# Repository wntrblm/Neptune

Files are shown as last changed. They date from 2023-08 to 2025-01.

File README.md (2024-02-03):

# Winterbloom Neptune

Neptune is a *salty* diode ladder filter.

More details available at https://winterbloom.com/shop/neptune

## Repository layout

This repository contains the hardware design files and user guide for Neptune:

- **factory/** contains the scripts used to program, test, and calibrate the module after assembly. These scripts are all written in Python.
- **hardware/** contains the hardware design files for the mainboard and blank panel, as well as hardware for automated testing. These are all created using KiCAD.
- **user_guide/** contains the user's guide source files. These are written in Markdown and published using MkDocs.
- **simulation/** contains the simulation used to design this filter. These should be opened using the Falstad CircuitJS simulator https://www.falstad.com/circuit/circuitjs.html.

## License and contributing

Neptune is open-source hardware and software, however, licensing a project like this is a little complicated. Please take a chance to review the [LICENSE](LICENSE.md) file.

We welcome contributions! Please read our [Code of Conduct](CODE_OF_CONDUCT.md) first.

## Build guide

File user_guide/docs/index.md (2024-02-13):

# Manual

Winterbloom's [Neptune][store-assembled] is a resonant diode ladder filter inspired by the designs of [Moritz Klein] and [Arturia]. It's intended to bring together sound and modulation into a complete, distinct synthesizer voice. Unlike typical multi-mode filters with separate modes or outputs, Neptune instead has separate low-pass and high-pass _inputs_ into a single filter core. This filter core is coupled with a feedback modulated distortion circuit called _salt_ that opens up a wide range of tonal possibilities from tame to dirty to outright chaotic.

[store-assembled]: https://winterbloom.com/shop/neptune
[store-kit]: https://winterbloom.com/shop/neptune-kit
[Moritz Klein]: https://www.youtube.com/@MoritzKlein0
[Arturia]: https://arturia.com

[TOC]

## Specifications

-   Available [assembled][store-assembled] or as a [kit][store-kit]
-   `12 HP`
-   `+12v @ 60 mA`, `-12v @ 50 mA`
-   `25mm` deep
-   Separate low pass & high pass inputs
-   Self-oscillating at high resonance levels
-   Salt feedback circuit
-   DC-coupled signal path
-   [ModularGrid page]

[modulargrid page]: https://www.modulargrid.net/e/winterbloom-neptune

## Getting support and help

We want you to have a wonderful experience with your module. If you need help or run into problems, please reach out to us. [Email] is the best way for product issues, whereas [Discord] and [GitHub][github issues] are great for getting advice and help on how to customize your module.

-   Send us [an email][email]
-   File a bug [on GitHub][github issues]
-   Reach out on the [Discord][discord]

[github issues]: https://github.com/wntrblm/Neptune/issues
[discord]: https://discord.gg/UpfqghQ
[email]: mailto:support@winterbloom.com

## Installation

Illustration of power connection

To install this into your Eurorack setup, connect a Eurorack power cable from your power supply to the back of the module. **Note that even though there's a keyed power connector on the module, double check that the red stripe is on the side labeled `red stripe`!** Once you've connected the power cable, secure your module to your rack rails using screws.

## Overview

Neptune illustration

Like other filters, Neptune _subtracts_ frequencies from audio signals. Unlike most other filters, however, Neptune is a single filter with separate inputs for low-pass and high-pass. If you use just one of these inputs at a time, Neptune will act as a familiar low-pass or high-pass filter. However, using both inputs at the same time opens up new possibilities for combining and filtering multiple signals.

Neptune is also a _resonant_ filter, which allows you to boost the frequencies around the cutoff frequency. Neptune rounds out its sonic character with _Salt_- a feedback modulation circuit that can add subtle grit when used sparingly and wild, chaotic distortion when applied with abandon.

Neptune belongs to _diode ladder_ family of filters. These filters are known for their characteristic "dirty" sound compared to the modern, popular "smooth" OTA family. Diode filters behave quite differently from their counterparts, exhibiting increasingly non-linear behavior when overdriven or operated with high resonance. Neptune itself shares a lot of similarities with the _Steiner_ filters found in Arturia's Brute series, but the addition of the salt feedback circuit allows for a broader range of unpredictable sounds.

Neptune is a collaboration between [Carson Walls] and [Winterbloom]. Carson crafted Neptune's voice, layout, and electronics design, while Thea & Maggie took on Neptune's visuals, interface, physical design, and manufacturing.

*[OTA]: Operational transconductance amplifier
[Carson Walls]: https://decapoddevices.com
[Winterbloom]: https://winterbloom.com

## Interface

### Audio inputs

Audio inputs

Neptune has separate audio inputs for low-pass and high-pass labeled with ++"lp"++ and ++"hp"++ respectively. Each input has its own volume control knob, where fully counterclockwise mutes the input. The mark at 2 o' clock indicates _unity gain_, where the input and output volume will be the same.

!!! fairy "Volume & resonance"
    Because of the architecture of this filter, the sound of the resonance is strongly affected by the input volume. The louder the input volume, the less obvious and "sweet" the resonance. If you want resonance to really catch the harmonics of the input, try reducing the input volume as you turn the resonance up.

### Audio output and volume

Audio output

Neptune's audio output, ++"out"++, has a built-in VCA for volume control. The ++"vol"++ input responds to a `0 to 5 V` signal with `0 V` completely muting the output and `5 V` giving maximum volume. When ++"vol"++ is left unpatched, the output volume defaults to maximum.

*[VCA]: Voltage-controlled amplifier

### Cutoff frequency

Cutoff frequency controls

Neptune dedicates several controls for the filter's _cutoff frequency_. Frequencies above the cutoff frequency are attenuated from the low-pass input signal, while frequencies below the cutoff are attenuated from the high-pass input signal.

The primary control for the cutoff frequency is the large cutoff knob labeled ++"♆"++. Turning the knob fully counterclockwise sets the cutoff frequency to near `0 Hz`, where the low-pass signal is almost entirely cut out while the high-pass signal is largely unaffected. Conversely, turning the knob fully clockwise sets the cutoff frequency to around `200 kHz`, where the low-pass signal is largely unaffected and the high-pass signal is cut out.

Audio inputs

The cutoff frequency set by the ++"♆"++ knob can be _modulated_ by two similar but distinct CV inputs labeled ++"fm1"++ and ++"fm2"++. Both inputs respond to `±5 V` signals but ++"fm1"++ has an _attenuverter_ while ++"fm2"++ has an _attenuator_.

The ++"fm1"++ _attenuverter_ controls both the _level_ and _polarity_ of ++"fm1"++'s CV input signal. At 12 o' clock, no signal is passed through. Turning clockwise gradually introduces the signal while turning counterclockwise gradually introduces an inverted version of the signal. The ring of LEDs around ++"fm1"++ indicate the polarity and level of modulation: blue indicates a positive signal, while red indicates a negative signal.

Similarly, the smaller ++"fm2"++ _attenuator_ controls just the _level_ of ++"fm2"++'s CV input signal. Fully counterclockwise completely attenuates the signal, while turning clockwise gradually introduces the signal. The white marking indicates where the cutoff frequency will roughly track at `1 Volt / octave`, but note that due to the way the filter works this will not track perfectly.

Finally, the LEDs around the ++"♆"++ knob indicate the total combined effect of ++"♆"++ along with the ++"fm1"++ & ++"fm2"++ inputs and controls. LEDs to the left of the knob indicate that more of the low-pass signal is being passed, while the LEDs to the right indicate that more of the high-pass signal is being passed.

!!! fairy "CV Range"
    Neptune's control voltages are nominally `±5 V`, but it's generally fine with voltages beyond this range. Just note that it may not respond as expected when you get far out of that range.

*[CV]: Control Voltage

### Resonance

Resonance controls

Neptune is a _resonant_ filter, and like other filters, resonance increases the volume of frequencies near the cutoff frequency. Neptune's resonance is controlled with the ++"reso"++ knob and CV input. The ++"reso"++ knob introduces more and more resonance as you turn the knob clockwise. When the ++"reso"++ knob is turned beyond the white dot the filter will begin self-oscillating, indicated with a red LED. Likewise, the ++"reso"++ CV input responds to `0 to 5 V` and is summed with the ++"reso"++ knob.

Unlike many filters, Neptune does not cut out bass frequencies as the resonance is turned up. While this preserves low-end frequencies, it can lead to the input volume overwhelming the resonance. If you want a "sweeter" resonance sound, try reducing the input volume when the resonance is turned up.

### Salt

Salt controls

Neptune includes a feedback modulation circuit called _Salt_. When used sparingly, salt can add a bit of subtle grit and sonic character to your sound. When used with gleeful abandon, salt will create increasingly chaotic distortion with harsh overtones.

Salt is controlled by the ++"salt"++ knob and CV input. The ++"salt"++ knob introduces more and more feedback modulation as you turn the knob clockwise. Keep in mind that salt and resonance are inherently linked and interact strongly, meaning that more resonance will increase salt's effect and vice versa. There are many textures to be found in different combinations of salt, resonance, and input volume.

## Example patches

If you're not sure where to start with Neptune this section has a few patches to get you up and running. Grab your patch cables, an oscillator, and an output module to follow along.

### Low-pass filter

The first patch creates a familiar *low-pass filter*:

Low pass filter patch

-   Turn the ++"reso"++ and ++"salt"++ knobs all the way counterclockwise
-   Turn the ++"♆"++ knob to 12 o' clock
-   Turn the small ++"lp"++ volume knob to about 2 o' clock
-   Patch an oscillator into the ++"lp"++ input jack
-   Patch the output jack to your rack's output or headphones module

Once patched, use the ++"♆"++ knob to sweep through the filter's frequency range. Try introducing some resonance using the ++"reso"++ knob and salt using the ++"salt"++ knob.

<winter-audio-player title="Low-pass filter sweep">
        <source src="./media/lp-sweep.flac" type="audio/flac" />
        <source src="./media/lp-sweep.m4a" type="audio/x-m4a" />
</winter-audio-player>
<winter-audio-player title="Resonant low-pass filter sweep">
    <source src="./media/resonant-lp-sweep.flac" type="audio/flac" />
    <source src="./media/resonant-lp-sweep.m4a" type="audio/x-m4a" />
</winter-audio-player>
<winter-audio-player title="Resonant, salty low-pass filter sweep">
    <source src="./media/resonant-salty-lp-sweep.flac" type="audio/flac" />
    <source src="./media/resonant-salty-lp-sweep.m4a" type="audio/x-m4a" />
</winter-audio-player>

### High-pass filter

The second patch is similar to the first and creates a *high-pass filter*:

High pass filter patch

-   Turn the ++"reso"++ and ++"salt"++ knobs all the way counterclockwise
-   Turn the ++"♆"++ knob to 12 o' clock
-   Turn the small ++"hp"++ volume knob to about 2 o' clock
-   Patch an oscillator into the ++"hp"++ input jack
-   Patch the output jack to your rack's output or headphones module

Once patched, use the ++"♆"++ knob to sweep through the filter's frequency range. Once again, try introducing some resonance using the ++"reso"++ knob and salt using the ++"salt"++ knob.

<winter-audio-player title="High-pass filter sweep">
    <source src="./media/hp-sweep.flac" type="audio/flac" />
    <source src="./media/hp-sweep.m4a" type="audio/x-m4a" />
</winter-audio-player>
<winter-audio-player title="Resonant high-pass filter sweep">
    <source src="./media/resonant-hp-sweep.flac" type="audio/flac" />
    <source src="./media/resonant-hp-sweep.m4a" type="audio/x-m4a" />
</winter-audio-player>
<winter-audio-player title="Resonant, salty high-pass filter sweep">
    <source src="./media/resonant-salty-hp-sweep.flac" type="audio/flac" />
    <source src="./media/resonant-salty-hp-sweep.m4a" type="audio/x-m4a" />
</winter-audio-player>

### High/low shelf filter

The next patch uses both inputs to create a high/low shelf filter:

High/low shelf filter patch

-   Turn the ++"reso"++ and ++"salt"++ knobs all the way counterclockwise
-   Turn the ++"♆"++ knob to 12 o' clock
-   Turn the small ++"lp"++ and ++"hp"++ volume knobs to about 12 o' clock
-   Using a multiple or stackcable, patch the *same* oscillator signal into both ++"lp"++ and ++"hp"++ input jacks
-   Patch the output jack to your rack's output or headphones module

Once patched, you can use the ++"lp"++ and ++"hp"++ volume knobs as your low- and high-pass shelves while the ++"Neptune ♆"++ knob controls the shelving frequency. You can use resonance as a frequency boost to *emphasize* the frequencies around the shelving frequency without cutting out the rest.

<winter-audio-player title="High/low shelf filter">
    <source src="./media/low-shelf-example.flac" type="audio/flac" />
    <source src="./media/low-shelf-example.m4a" type="audio/x-m4a" />
</winter-audio-player>

### Spectral crossfader

The next patch uses different signals on both inputs to create a *spectral* crossfader:

Spectral crossfader patch

-   Turn the ++"reso"++ and ++"salt"++ knobs all the way counterclockwise
-   Turn the ++"♆"++ knob to 12 o' clock
-   Turn the small ++"lp"++ and ++"hp"++ volume knobs to about 2 o' clock
-   Patch two different signals into the ++"lp"++ and ++"hp"++ input jacks
-   Patch the output jack to your rack's output or headphones module

Once patched, you can use the ++"♆"++ knob to crossfade between the frequency contents of the two signals, picking out the low frequencies of one signal and the high frequencies of the other.

<winter-audio-player title="High/low-pass crossfade">
    <source src="./media/lp-hp-crossfade.flac" type="audio/flac" />
    <source src="./media/lp-hp-crossfade.m4a" type="audio/x-m4a" />
</winter-audio-player>

### Self-oscillation

The final patch explores *self-oscillation*:

Self-oscillation patch

-   Leave the ++"lp"++ and ++"hp"++ input jacks unpatched
-   Turn the ++"salt"++ all the way counterclockwise
-   Turn the ++"♆"++ knob to around 10 or 11 o' clock
-   Turn the ++"reso"++ knob up to the self-oscillation point marked with the white dot, just past 2 o' clock
-   Patch the output jack to your rack's output or headphones module

Once patched, the filter should be self-oscillating and generating a sine waveform. You can use the ++"♆"++ knob to set the output signal's frequency. If you further increase resonance past the white dot, the waveform will saturate and become more harsh, like a square wave. Adding salt will cause the waveform to become more unstable and chaotic.

<winter-audio-player title="Clean self-oscillation">
    <source src="./media/clean-self-oscillation-sweep.flac" type="audio/flac" />
    <source src="./media/clean-self-oscillation-sweep.m4a" type="audio/x-m4a" />
</winter-audio-player>
<winter-audio-player title="Full self-oscillation">
    <source src="./media/full-self-oscillation-sweep.flac" type="audio/flac" />
    <source src="./media/full-self-oscillation-sweep.m4a" type="audio/x-m4a" />
</audio>
<winter-audio-player title="Salty self-oscillation">
    <source src="./media/salty-self-oscillation-sweep.flac" type="audio/flac" />
    <source src="./media/salty-self-oscillation-sweep.m4a" type="audio/x-m4a" />
</winter-audio-player>

## Further explorations

These ideas go beyond the example patches and may help you explore Neptune's uses and sonic possibilities.

### Basic synth voice

<winter-audio-player title="Basic low-pass synth voice">
    <source src="./media/simple-low-pass-filter-synth-voice-loop.flac" type="audio/flac" />
    <source src="./media/simple-low-pass-filter-synth-voice-loop.m4a" type="audio/x-m4a" />
</winter-audio-player>

Use any oscillator as the input for the ++"lp"++ in, preferably with a sharp waveform like a saw or square. Use an envelope going the ++"fm1"++ and ++"vol"++ inputs. Trigger the envelope with a gate source from a keyboard or sequencer. Adjust the envelope timings to get long drones notes, or quick percussive ones. Adjust the cutoff frequency, ++"fm1"++ amount, resonance, and salt to hear the range of possible sounds from the low-pass filter.

### Spectral crossfading synth voice

<winter-audio-player title="Spectral crossfading synth voice" loop>
    <source src="./media/crossfading-synth-voice-loop.flac" type="audio/flac" />
    <source src="./media/crossfading-synth-voice-loop.m4a" type="audio/x-m4a" />
</winter-audio-player>

Patch one oscillator to the ++"lp"++ input and another oscillator to the ++"hp"++ input, or use different waveforms from the same oscillator. Make sure the oscillators are tuned close to each other for the most harmonious sound. Listen to how the filter can fade between the frequencies of the two oscillator signals. Plug one envelope to ++"fm1"++ and a different envelope to ++"vol"++. Trigger the envelopes with the same gate source, such as a keyboard or sequencer. Try different envelope shapes to get different responses, and listen to how different input signals and volumes effect the sound. Try different oscillator tunings, at octaves or ratios for nice harmonic sounds, or detuned for more dissonant ones.

### Kick drum voice

<winter-audio-player title="Kick drum voice">
    <source src="./media/kick-drum-voice.flac" type="audio/flac" />
    <source src="./media/kick-drum-voice.m4a" type="audio/x-m4a" />
</winter-audio-player>

Leave the ++"lp"++ and ++"hp"++ inputs unpatched. Turn ++"reso"++ up until the filter starts self oscillating. Send a fast, exponential envelope to ++"fm1"++ input and a second slower envelope to ++"vol"++. The fast exponential envelope is the kick drum’s pitch sweep, whose intensity is adjusted with the ++"fm1"++ attenuverter. Adjust the cutoff frequency to set the base pitch of the drum sound, for example set it to around 9 o’clock for a low bass drum sound. Try increasing the resonance or adding salt to increase the grittiness of the drum.

### Chaotic oscillator

<winter-audio-player title="Chaotic oscillator">
    <source src="./media/chaotic-oscillation.flac" type="audio/flac" />
    <source src="./media/chaotic-oscillation.m4a" type="audio/x-m4a" />
</winter-audio-player>

Leave the ++"lp"++ and ++"hp"++ inputs unpatched and turn ++"reso"++ up until the filter starts self oscillating. Turn ++"salt"++ up until it *just* starts to get chaotic. The filter cutoff frequency will twist and wobble around, making a chaotic output which is a combination of feedback effects. Try adjusting the cutoff frequency, resonance, and salt to get a whole spectrum of sounds, from stable and harmonious, to wild and unstable.

### Drum effects

<winter-audio-player title="Drum effects">
    <source src="./media/drum-effects.flac" type="audio/flac" />
    <source src="./media/drum-effects.m4a" type="audio/x-m4a" />
</winter-audio-player>

Send a drum mix, such as a recording or a mix of synthesized drums, to both the ++"lp"++ and ++"hp"++ inputs. This will make the filter act like [a shelf filter](#highlow-shelf-filter). The ++"lp"++ and ++"hp"++ volume knobs act as the level for the low shelf and the high shelf, while the cutoff frequency controls the crossover point of the shelves. Try adding a bit of resonance, lowering the high pass volume a bit to make a low shelf filter, and adjusting the cutoff frequency to target specific frequencies in the drum mix. For example try to emphasizing the snare or getting rid of some of the high frequencies without cutting them out completely like on a traditional low pass filter.

### Loop crossfader

Use a device like an [Octatrack], [Digitakt], or any sampler that can output two different loops matched to the same tempo. If you only have a stereo output, you can hard-pan the loops to left and right channel before patching. Send one loop to the ++"lp"++ input and the other loop to the ++"hp"++ input. Adjusting the cutoff frequency will allow you to fade between the frequencies of the two loops. If the cutoff knob is fully clockwise you'll only hear the loop in the ++"lp"++ input, while if it's counterclockwise you'll only hear the loop in the ++"hp"++ input. You can adjust it to pick out the high frequencies of one loop, such as the cymbals, and the low frequencies of another loop, such as the bass drum.

[Octatrack]: https://www.elektron.se/us/octratrack-mkii-explorer
[Digitakt]: https://www.elektron.se/us/digitakt-explorer

### CV filter

Neptune is *technically* DC-coupled, so will pass and filter CV signals just as it does audio signals. If you send a signal to the ++"lp"++ input then Neptune will act like a *slew limiter*, limiting how fast the signal can move. If you use the ++"hp"++ input then Neptune will act like a gate to trigger converter, where sudden changes will be passed through but the output will settle back to the value at the ++"lp"++ input. Increasing resonance will cause Neptune to overshoot the input value and "ring".

Note that while Neptune can do some fun stuff with CV, it's very much designed with audio in mind which brings some limitations. First, the lowest cutoff frequency that the ++"♆"++ knob can reach is around `5 Hz`, however, you can use the ++"fm1"++ input along with its attenuverter to push the cutoff frequency even lower. Second, Neptune wasn't really designed for DC accuracy so it won't work well with sensitive CV signals like `1 V / Octave` pitch signals. Finally, Neptune's output can have a DC offset of up to `±2 V`, however, you can mitigate this a bit by mixing a constant voltage in with the ++"lp"++ input.

## Open source hardware & software

Neptune is completely open source and hacking is encouraged.

The [hardware design][hardware source] is available under the permissive [CERN-OHL-P v2] license, and is designed using [KiCAD], which is also free and open source. You can open the hardware files using [KiCAD], or you can download a PDF of the [schematics].

Open Source Hardware Association mark Neptune is [certified open source hardware][oshwa certification].

[hardware source]: https://github.com/wntrblm/Neptune/tree/main/hardware
[schematics]: https://github.com/wntrblm/Neptune/raw/main/hardware/board/mainboard.pdf
[CERN-OHL-P v2]: https://cern-ohl.web.cern.ch/
[KiCAD]: https://kicad.org/
[oshwa certification]: https://certification.oshwa.org/us002605.html

## Warranty, disclaimers, and limits

Modules purchased from Winterbloom have a warranty of six months from the date of purchase. This warranty covers any manufacturing defects in the module. It does not cover damage due to incorrect handling, storage, power, overvoltage events, or modifications.

Please [contact us][email] if you are experiencing issues with your module. Modules returned under warranty will either be refunded, replaced, or repaired at our discretion. You will be responsible for the cost of returning the module to Winterbloom.

Because Eurorack has a vast number of possible combinations of power supplies, modules, cases, and accessories, it is impossible for us to guarantee compatibility with every possible configuration. We make a reasonable effort to test modules with several power supplies, cases, and other modules.

We encourage tinkering, however, we will not refund, repair, or replace any products that have been modified.

We have stress tested Neptune under the following conditions. These are provided for reference only; we do not guarantee that the module will function under these conditions.

-   Continuous run time: at least `48 hours`
-   Overvoltage from power supply: at least `±20 V`
-   Reverse voltage from power supply: at least `±24 V`
-   Undervoltage from power supply: as low as `±8 V`
-   Over and under voltage on inputs: at least `±11 V`
-   Output shorted to ground: at least `60 minutes`

[email]: mailto:support@winterbloom.com

## Acknowledgments and thanks

Neptune would not be possible without the excellent educational YouTube videos by [Moritz Klein], and the help of him and others on his discord server. We would also like to acknowledge the following individuals for their outstanding support:

- Sarah Ocean, for coming up with the name "Salt"
- Izaak Hollander, for endless enthusiasm and beta testing
- Ben Wilson, for being a well of knowledge and incredible talent
- Jeremy Leaird-Koch, for wringing delights from Neptune in ways only he could
- Stijn & Priscilla Haring-Kuipers, for their guidance and insight

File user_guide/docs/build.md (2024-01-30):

---
title: Kit build guide
---

# Build

Welcome to the build guide for Neptune's DIY kit. We hope you have a great time putting this module together and a wonderful time using it.

Please **read all instructions** thoroughly before starting. If you have questions or run into trouble please reach out to us on [discord] or drop us [an email][email].

This is a **beginner level** kit. Some soldering experience is helpful but not required, though we recommend practicing on another project first. We also have some slightly easier kits available, such as our [Helium kit]. Even if you've got some experience, we recommend taking a look at [Adafruit's guide to excellent soldering][adafruit soldering guide].

This build takes around **one hour** to complete.

[TOC]

[discord]: https://discord.gg/UpfqghQ
[email]: mailto:support@winterbloom.com
[Helium kit]: https://winterbloom.com/shop/helium-kit
[adafruit soldering guide]: https://learn.adafruit.com/adafruit-guide-excellent-soldering

## Tools required

Before you begin, make sure that you've got:

-   Safety glasses. Yes, **really**. A pair like [these][safety glasses] are fine.
-   Proper ventilation, like this [small filtered fan](https://a.co/d/eUfPCRO).
-   A **temperature-controlled** soldering iron, like this [Hakko] or the [Pinecil]. It is very important to use a temperature-controlled iron, since unregulated irons can easily get hot enough to damage components. You should set your iron temperature based on your solder manufacturer's recommendations.
-   Solder. We recommend [Adafruit's SAC305 solder][adafruit solder] or [Kester 275 K100LD].
-   A small flat head screwdriver, like [this one][small screwdriver].

!!! question "Flux"
    We suggest using solder with "no clean" flux. If you use a different kind of flux, be sure to carefully clean the flux residue off based on the guidelines provided by the manufacturer of your solder. Take special care with the LEDs and potentiometers, as they can be damaged by water and flux cleaners.

[safety glasses]: https://a.co/d/dMXvPP6
[tweezers]: https://www.adafruit.com/product/422
[Hakko]: https://www.adafruit.com/product/1204
[Pinecil]: https://pine64.com/product/pinecil-smart-mini-portable-soldering-iron/
[adafruit solder]: https://www.adafruit.com/product/734
[Kester 275 K100LD]: https://www.kester.com/products/product/275-flux-cored-wire
[flux pen]: https://www.sra-solder.com/sra-312-no-clean-flux-pen-refillable
[small screwdriver]: https://lovemyswitches.com/2mm-flat-head-screwdriver-for-knob-set-screws/

## Kit contents

Your kit should contain the following items. If any are missing please [email us][email].

<winter-image-map src="../images/kit/kit-contents.svg">
    <winter-image-map-item id="mainboard">Mainboard</winter-image-map-item>
    <winter-image-map-item id="faceplate">Faceplate</winter-image-map-item>
    <winter-image-map-item id="jacks">1/8" jacks (8)</winter-image-map-item>
    <winter-image-map-item id="jack-nuts">Hex nuts for the 1/8" jacks (8)</winter-image-map-item>
    <winter-image-map-item id="power-header">Eurorack power header</winter-image-map-item>
    <winter-image-map-item id="rubber-bands">Rubber bands (2)</winter-image-map-item>
    <winter-image-map-item id="big-knob">Big knob</winter-image-map-item>
    <winter-image-map-item id="small-knob">Small knobs (3)</winter-image-map-item>
    <winter-image-map-item id="trimpots">Tall trimmer pots (3)</winter-image-map-item>
    <winter-image-map-item id="pots">9mm pots (4)</winter-image-map-item>
    <winter-image-map-item id="pot-washers">Washers for 9mm pots (4)</winter-image-map-item>
    <winter-image-map-item id="pot-nuts">Nuts for 9mm pots (4)</winter-image-map-item>
</winter-image-map>

- (1) Mainboard
- (1) Faceplate
- (8) 1/8" jacks
- (8) Hex nuts for the 1/8" jacks
- (3) Tall trimmer pots
- (4) 9mm pots
- (4) Washers & nuts for the 9mm pots
- (3) Small knobs
- (1) Large knob
- (1) Eurorack power header
- (2) Rubber bands

!!! fairy "Pot washers?"
    We typically screw the 9mm pot's washer and nut onto the shaft when packing kits so they don't get lost. You should remove them before you start the build!

## Power header

Your first task is to solder the 10-pin Eurorack power connector to the mainboard.

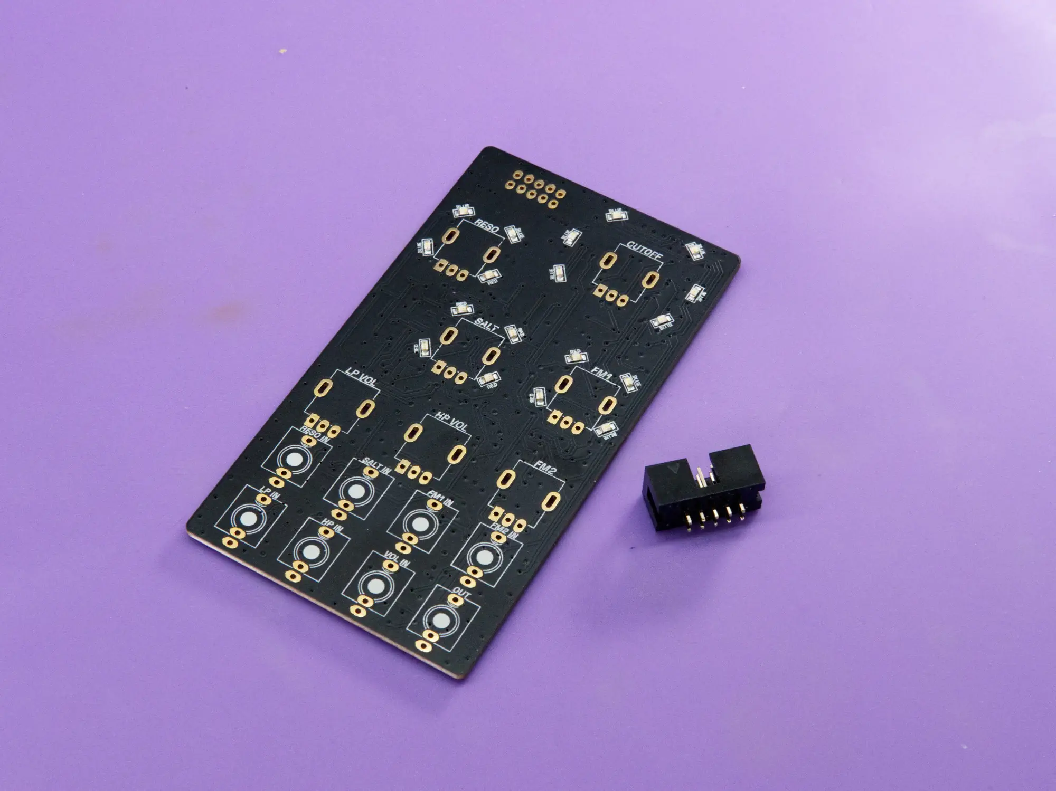
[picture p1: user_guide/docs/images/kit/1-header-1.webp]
Power header and mainboard


The power connector goes on the **back** side of the board. When placing **note the notch in the outline on the board**. You'll need to make sure the **slot on the connector matches where the notch is on the outline**. The holes for the power connector are designed to be a tight fit, so make sure to push the header firmly flush against the board.

<winter-carousel>
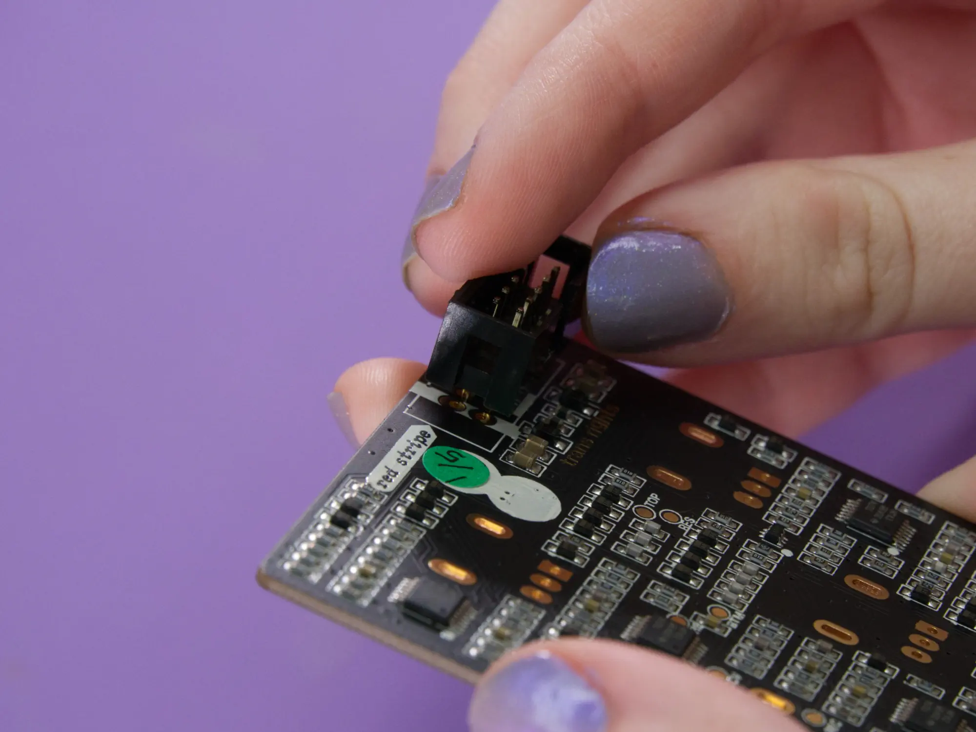
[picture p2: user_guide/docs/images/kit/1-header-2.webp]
  
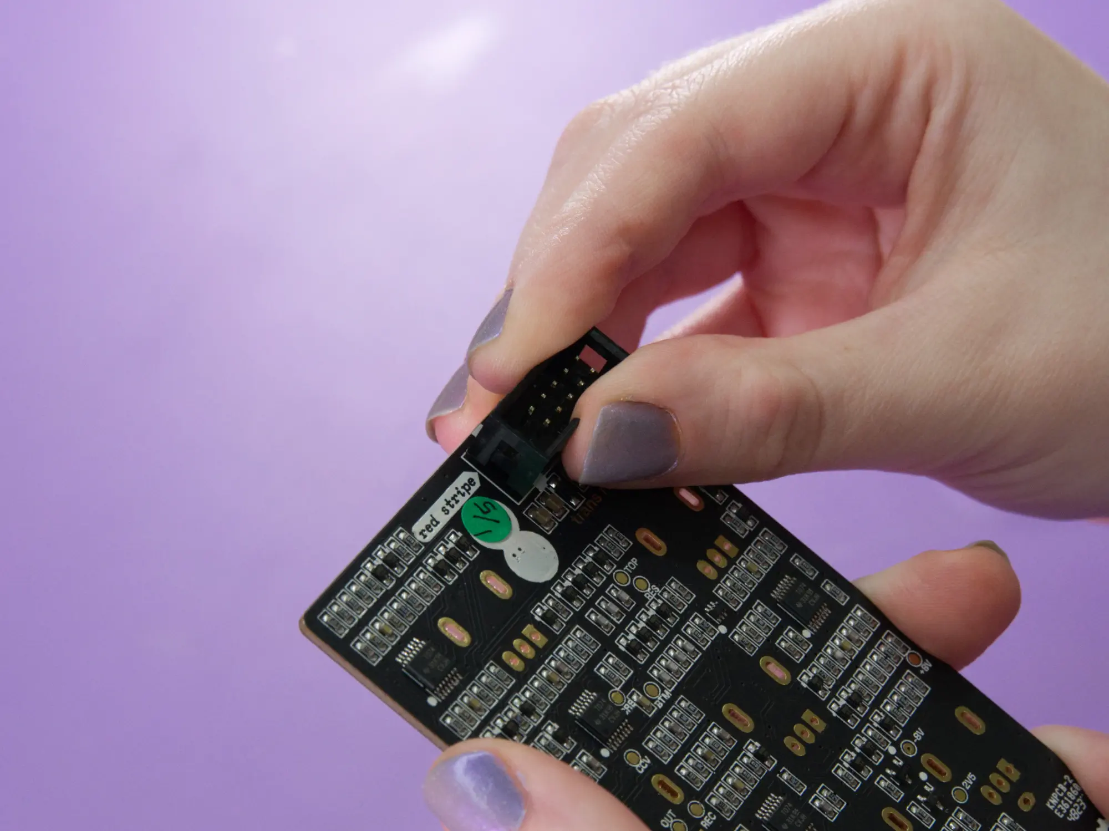
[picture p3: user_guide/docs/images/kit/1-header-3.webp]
  
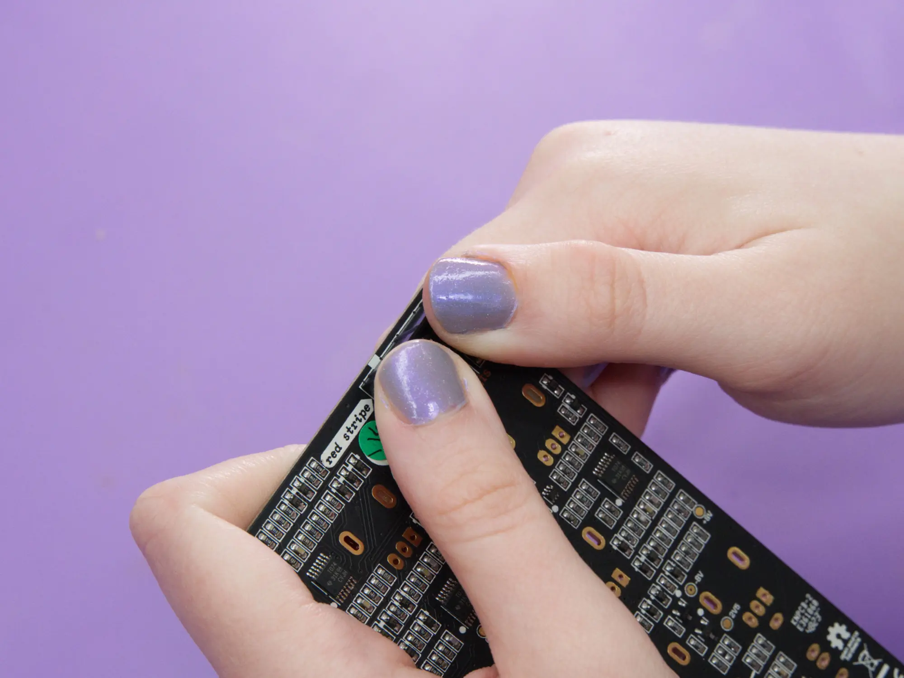
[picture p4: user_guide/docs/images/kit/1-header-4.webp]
  
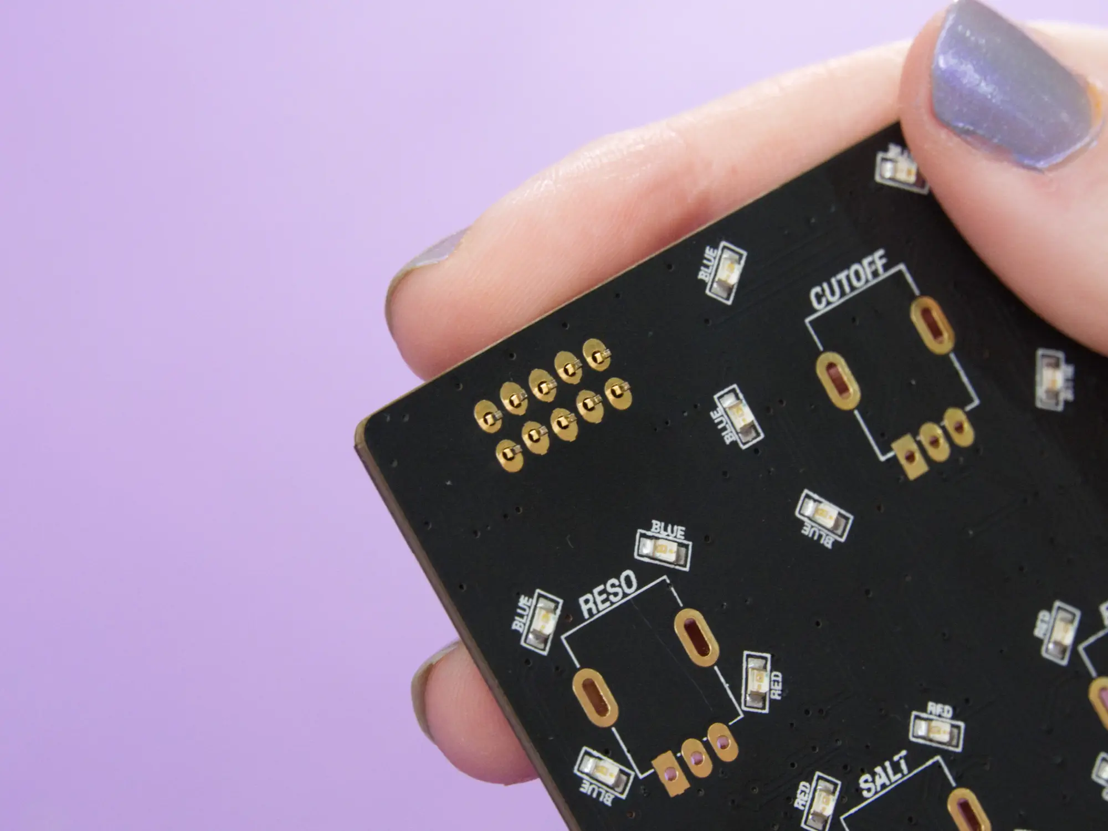
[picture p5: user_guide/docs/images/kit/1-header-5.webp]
  
</winter-carousel>

Once placed, make sure to push it flush against the board and then solder the 10 pins on the front side of the board.

<winter-carousel>
  
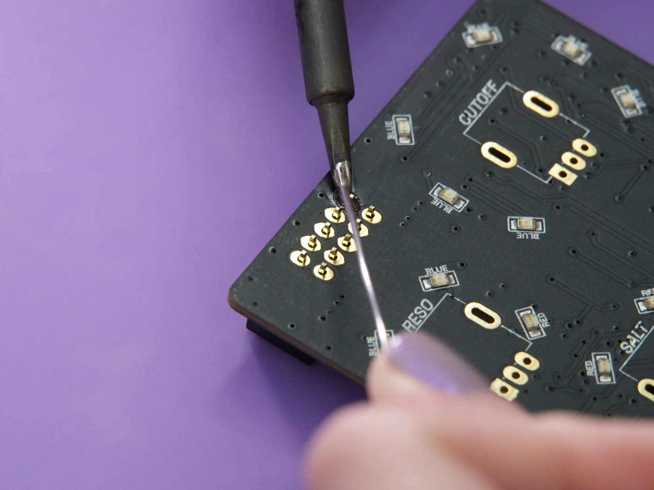
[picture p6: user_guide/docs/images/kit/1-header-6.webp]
  
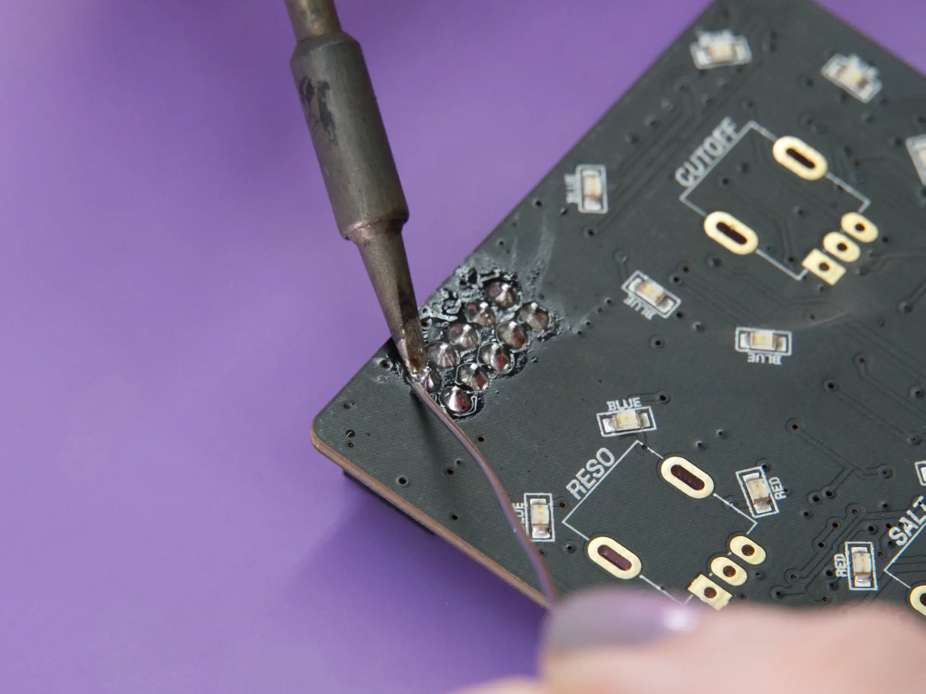
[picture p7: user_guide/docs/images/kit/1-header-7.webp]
  
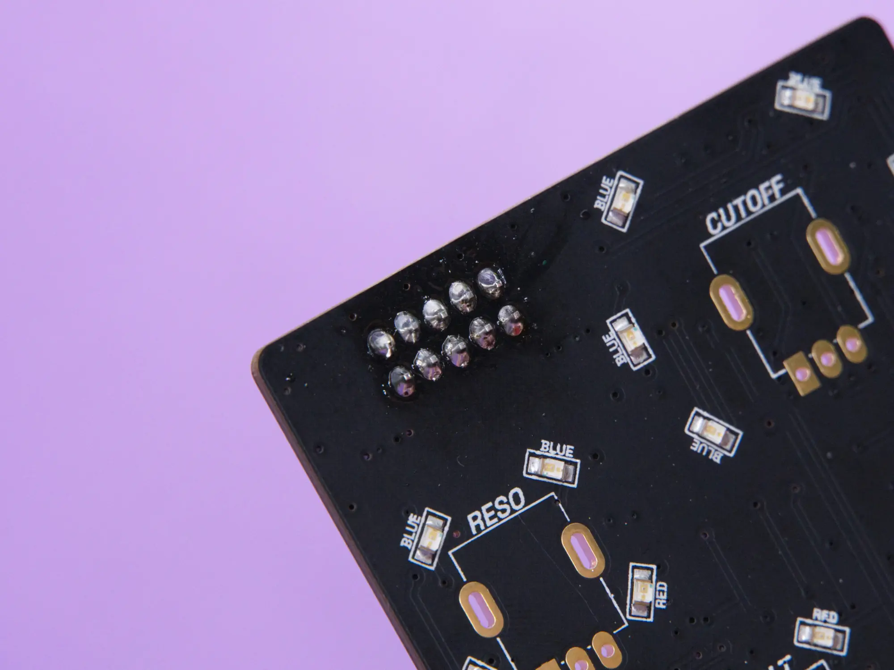
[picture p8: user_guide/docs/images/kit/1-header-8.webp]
  
</winter-carousel>

!!! warning "Watch out for those LEDs!"
    Avoid touching the LEDs with your iron- they really don't like being melted and they're very hard to replace.

## Pots and jacks

Your next task is to put all of the jacks and pots into place. **Don't solder these yet**, as you'll use the faceplate to help you get everything aligned in the next step.

!!! fairy "Stuffing"
    Fun fact, we call this process "stuffing"! It makes us think of Thanksgiving. 🦃

Start with the four `9mm pots`. Place them onto upper area of mainboard in the spots labeled `cutoff`, `reso`, `salt`, and `fm1`. You may need to bend or straighten the mounting legs on the pots to get them in place.

<winter-carousel>
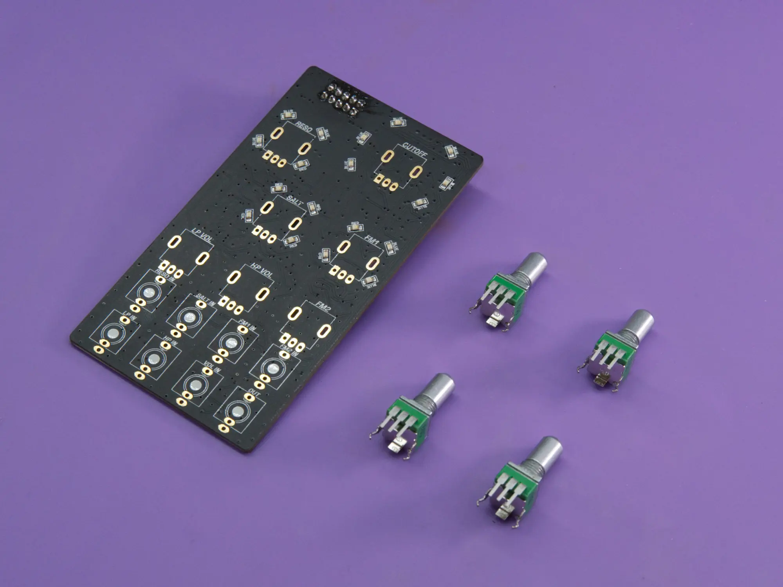
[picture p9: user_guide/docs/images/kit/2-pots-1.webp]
  
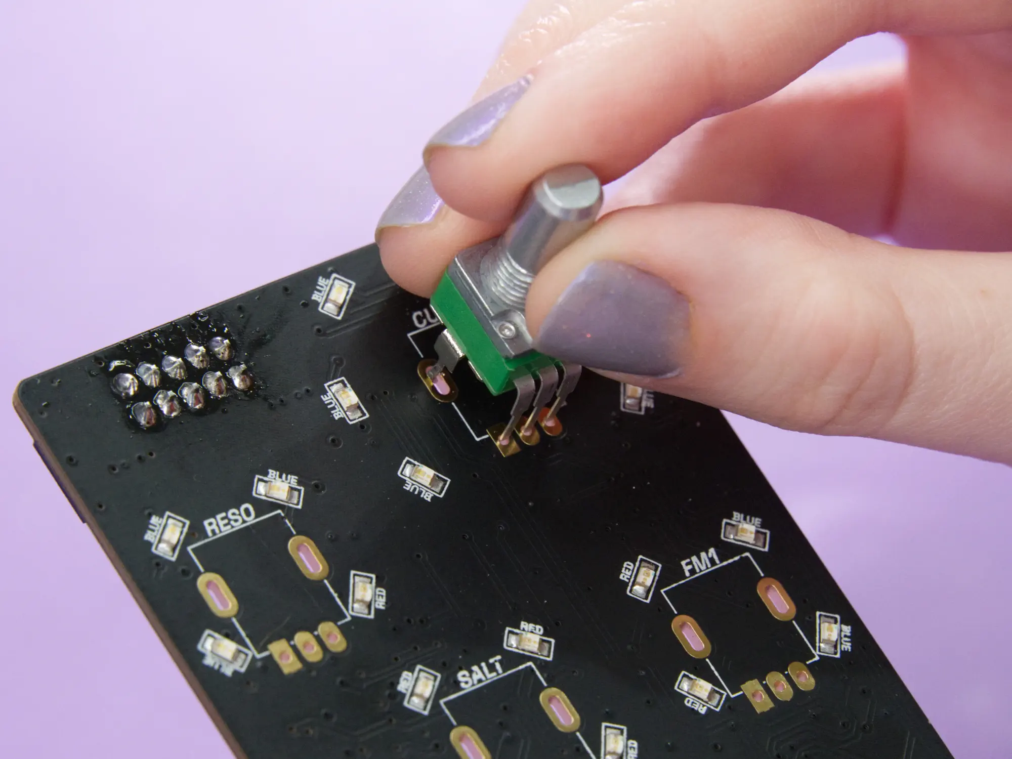
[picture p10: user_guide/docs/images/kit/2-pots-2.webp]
  
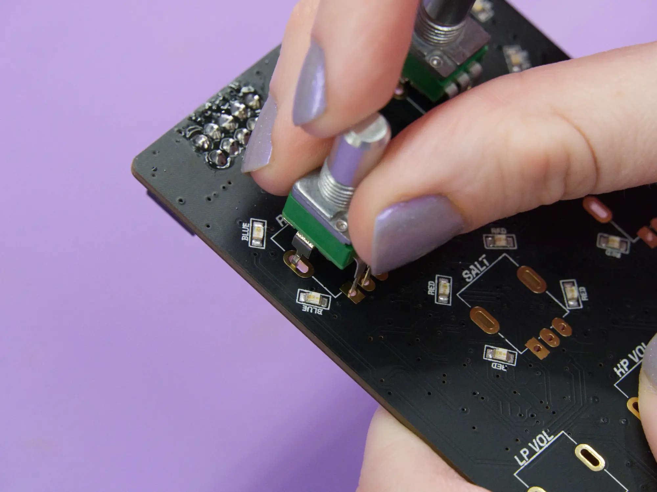
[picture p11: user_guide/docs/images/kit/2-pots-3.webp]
  
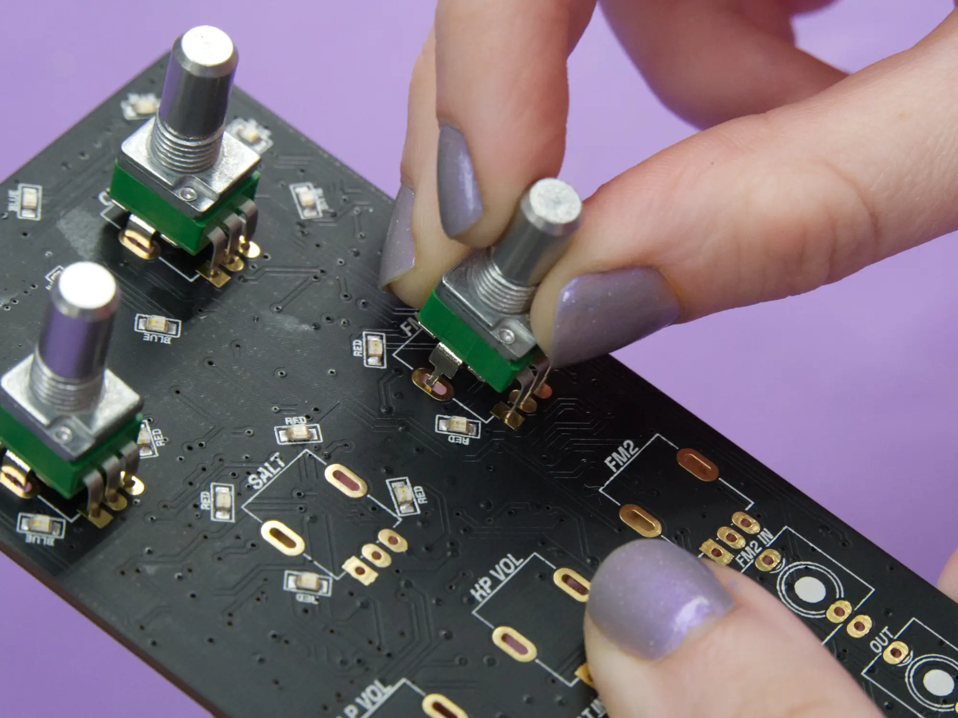
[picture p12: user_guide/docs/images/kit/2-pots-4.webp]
  
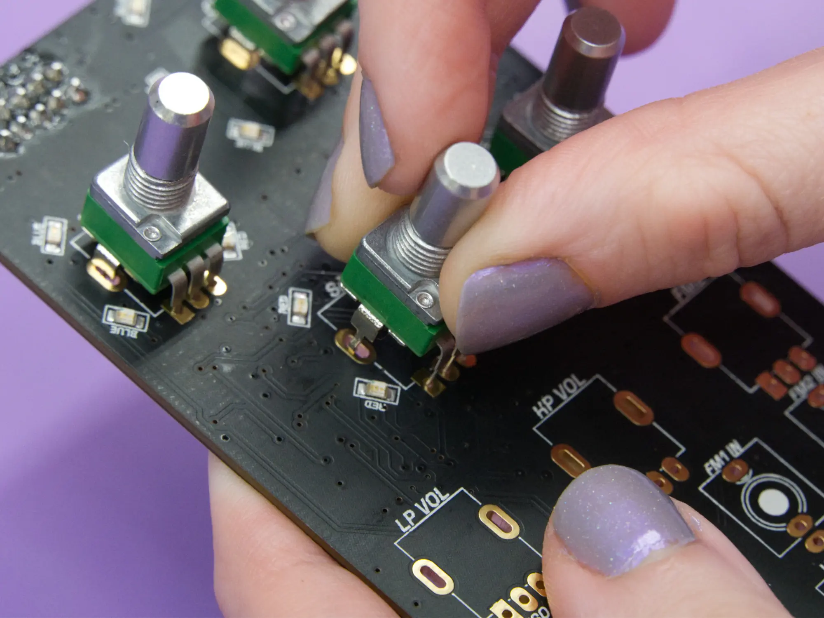
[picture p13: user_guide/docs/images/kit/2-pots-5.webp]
  
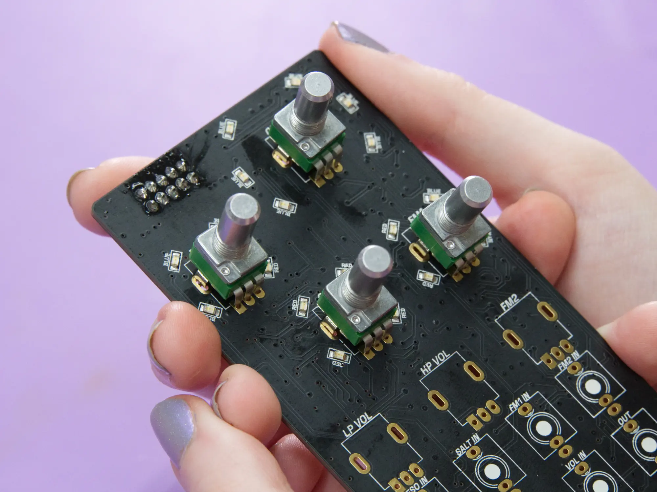
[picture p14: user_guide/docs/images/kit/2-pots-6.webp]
  
</winter-carousel>

Next up is the 3 `Tall trimmer pots`. Place these into the three spots in the middle of the mainboard labeled `lp vol`, `hp vol`, and `fm2`.

<winter-carousel>
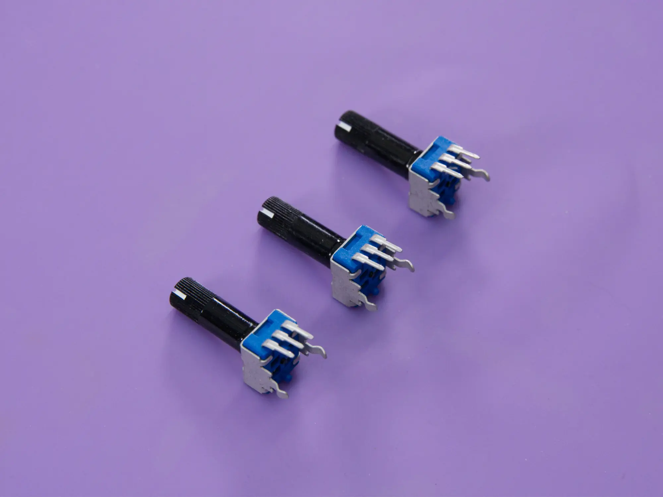
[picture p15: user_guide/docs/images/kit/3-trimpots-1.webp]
  
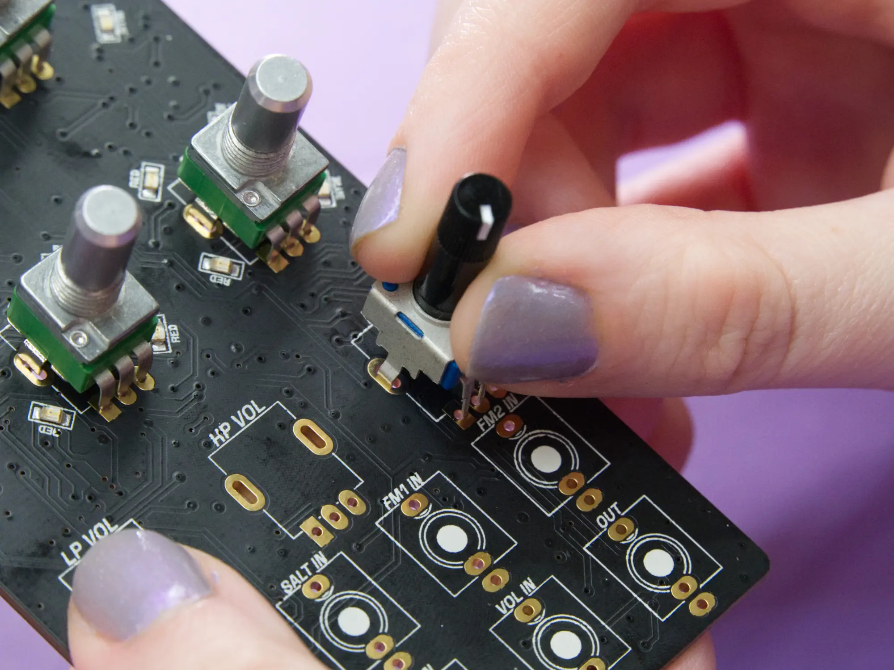
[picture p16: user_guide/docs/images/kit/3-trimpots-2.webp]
  
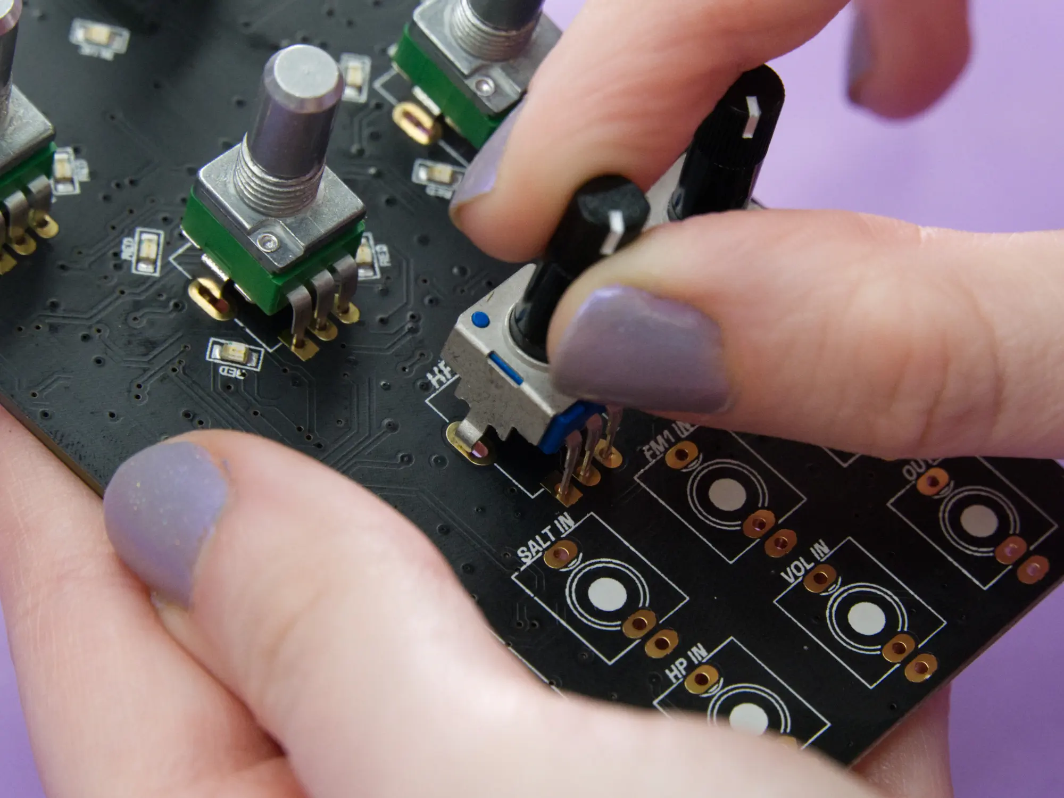
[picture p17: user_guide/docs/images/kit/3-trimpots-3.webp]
  
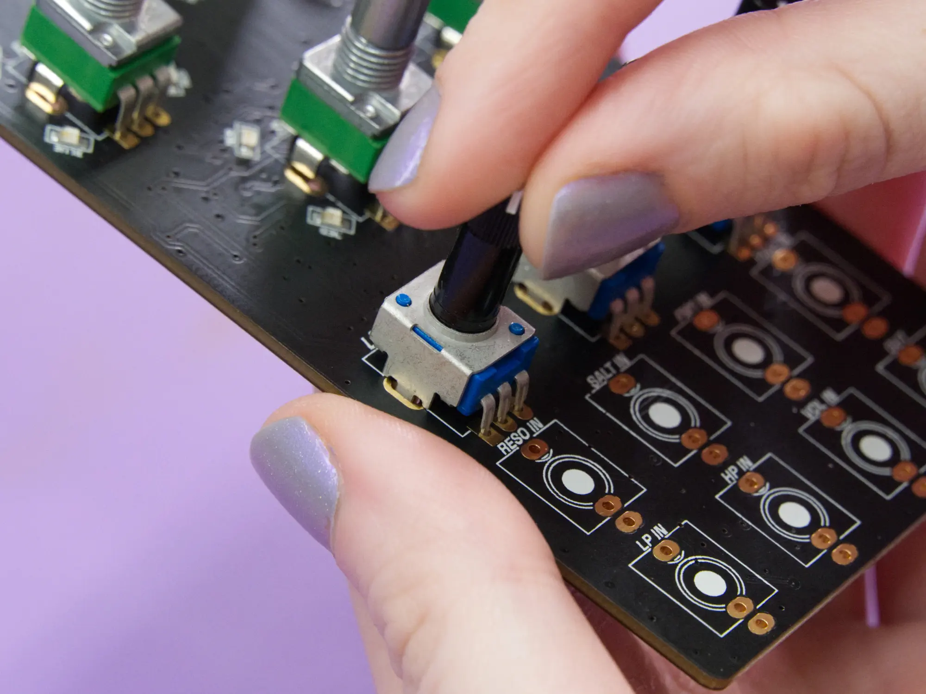
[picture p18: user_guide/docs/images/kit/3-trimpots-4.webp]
  
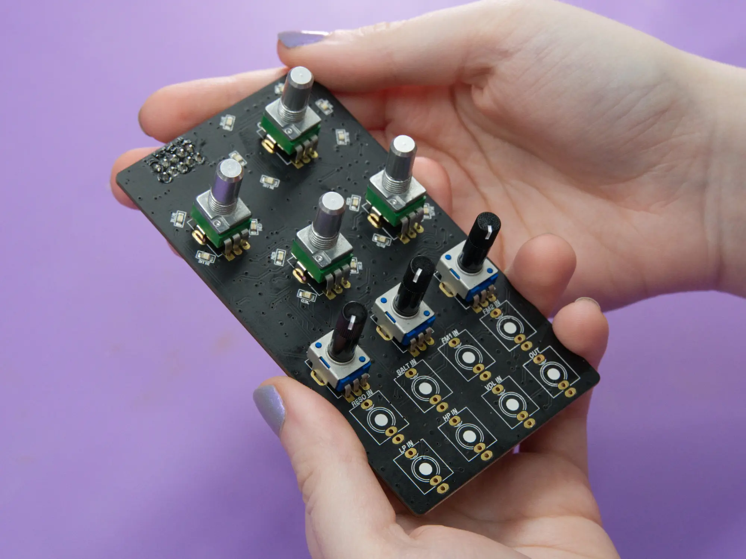
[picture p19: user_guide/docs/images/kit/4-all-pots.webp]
  
</winter-carousel>

Finally, the `1/8" jacks`. These go on the lower area of the mainboard in the spots labeled `reso in`, `salt in`, `fm1 in`, `fm2 in`, `lp in`, `hp in`, `vol in`, and `out`.

<winter-carousel>
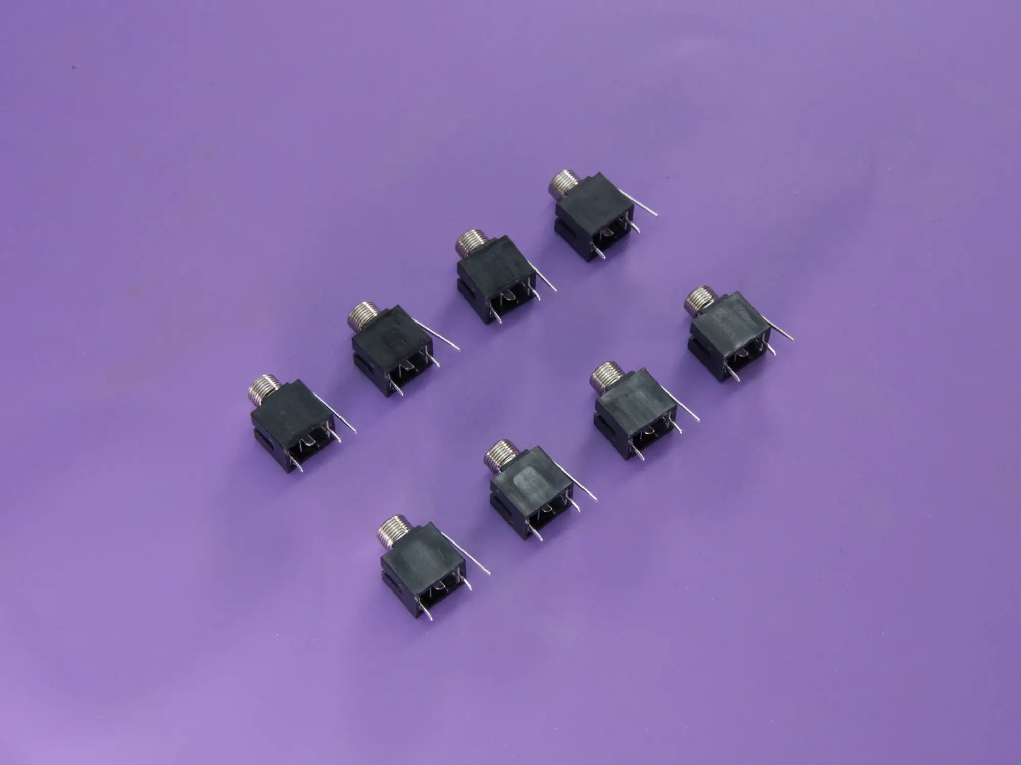
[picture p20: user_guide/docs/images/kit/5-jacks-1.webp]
  
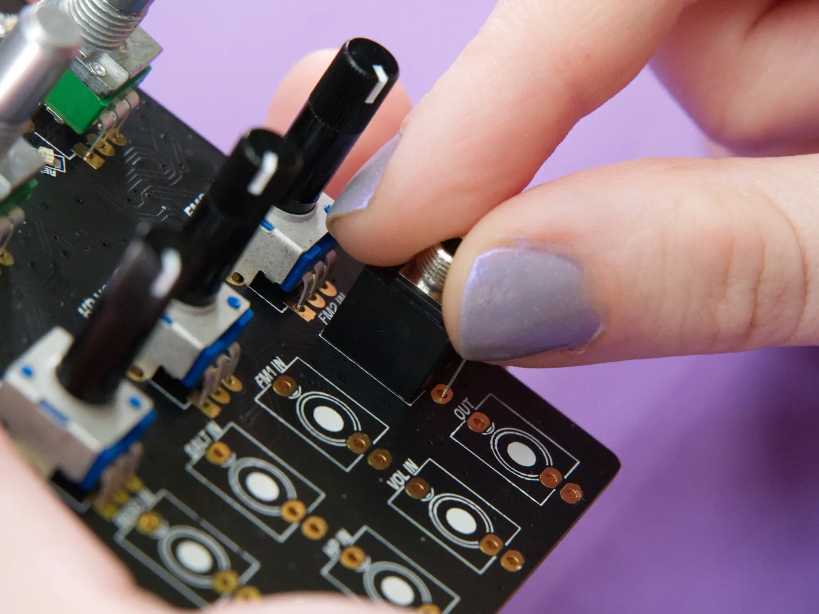
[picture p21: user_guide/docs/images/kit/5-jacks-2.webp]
  
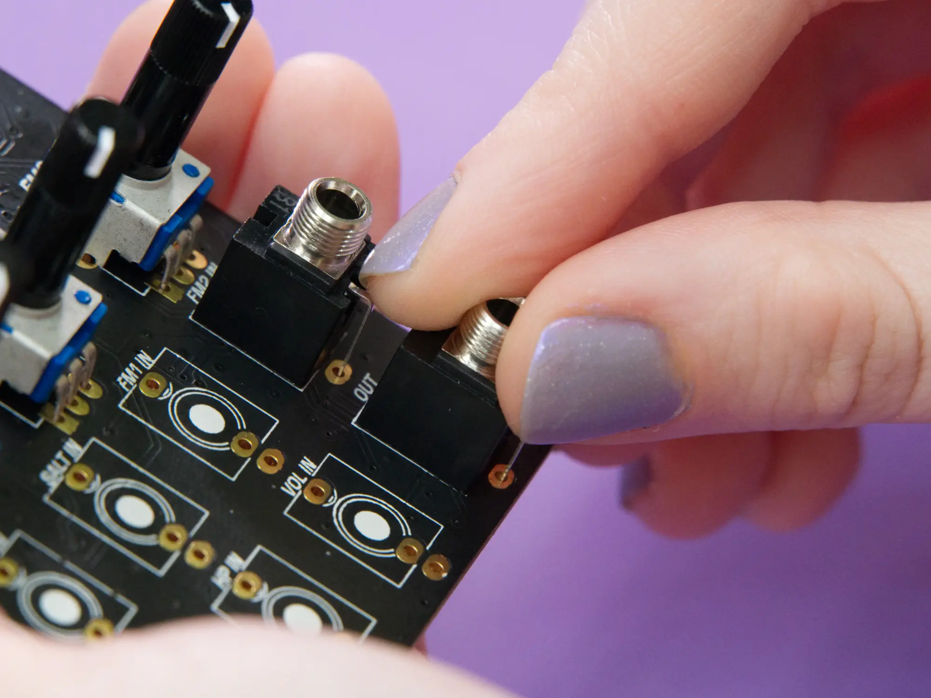
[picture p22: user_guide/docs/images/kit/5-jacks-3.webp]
  
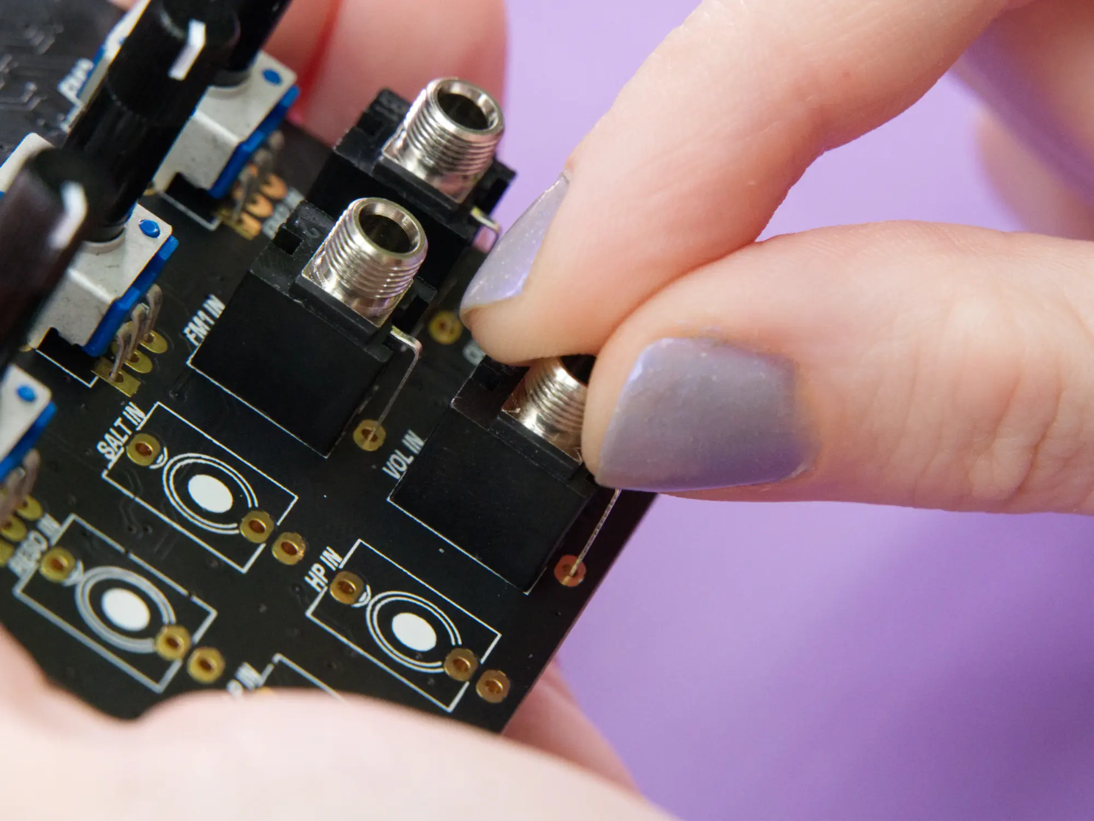
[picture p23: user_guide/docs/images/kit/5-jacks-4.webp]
  
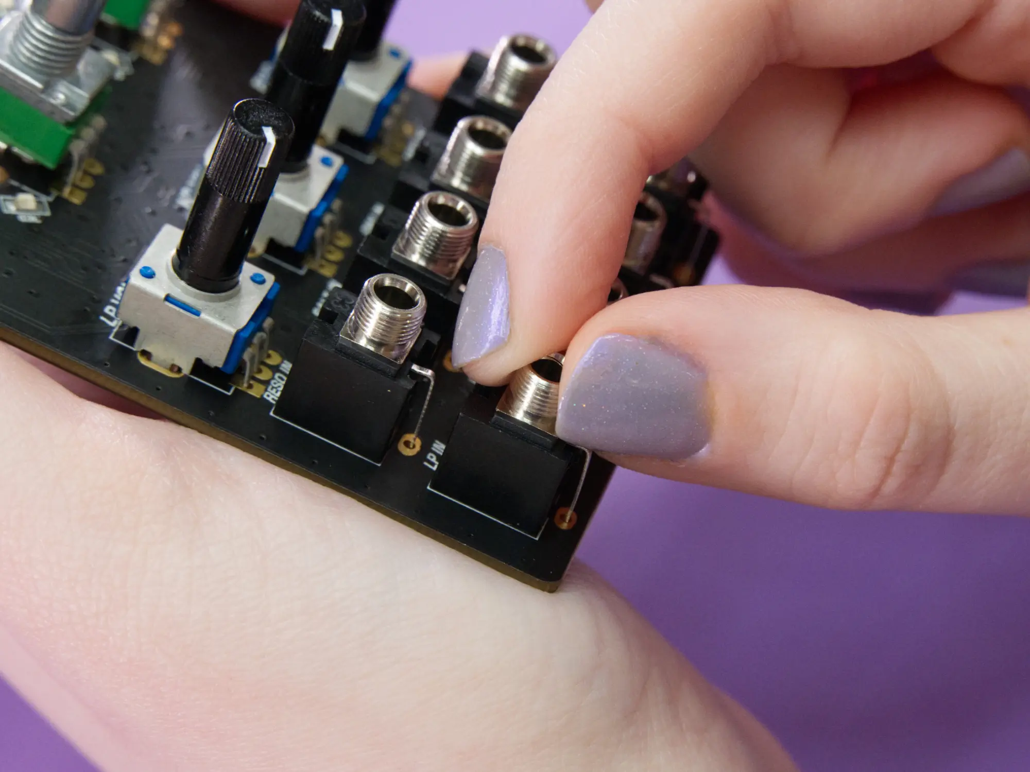
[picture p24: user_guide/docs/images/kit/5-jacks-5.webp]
  
</winter-carousel>

At this point you should have all the jacks and pots in place:

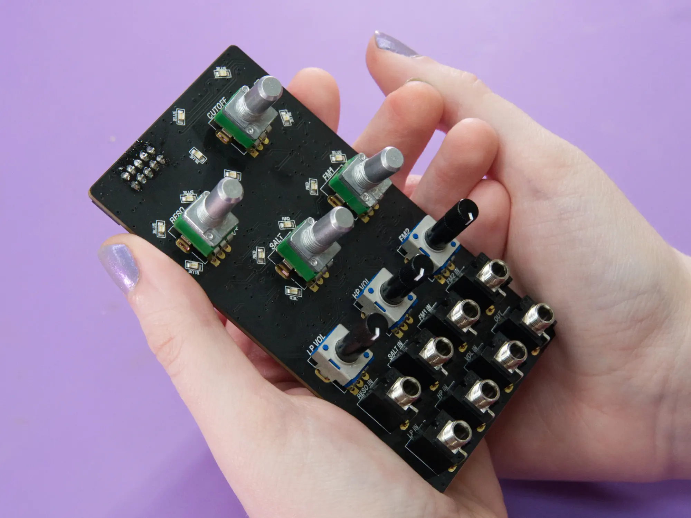
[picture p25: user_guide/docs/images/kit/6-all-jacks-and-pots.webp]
All things stuffed


## Faceplate alignment

Before you get down to soldering, your next task is to use the faceplate to make sure everything is aligned and hold it all in place while you work. Grab the `faceplate` and the two `rubber bands` and then carefully place the faceplate over the jacks and pots.

<winter-carousel>
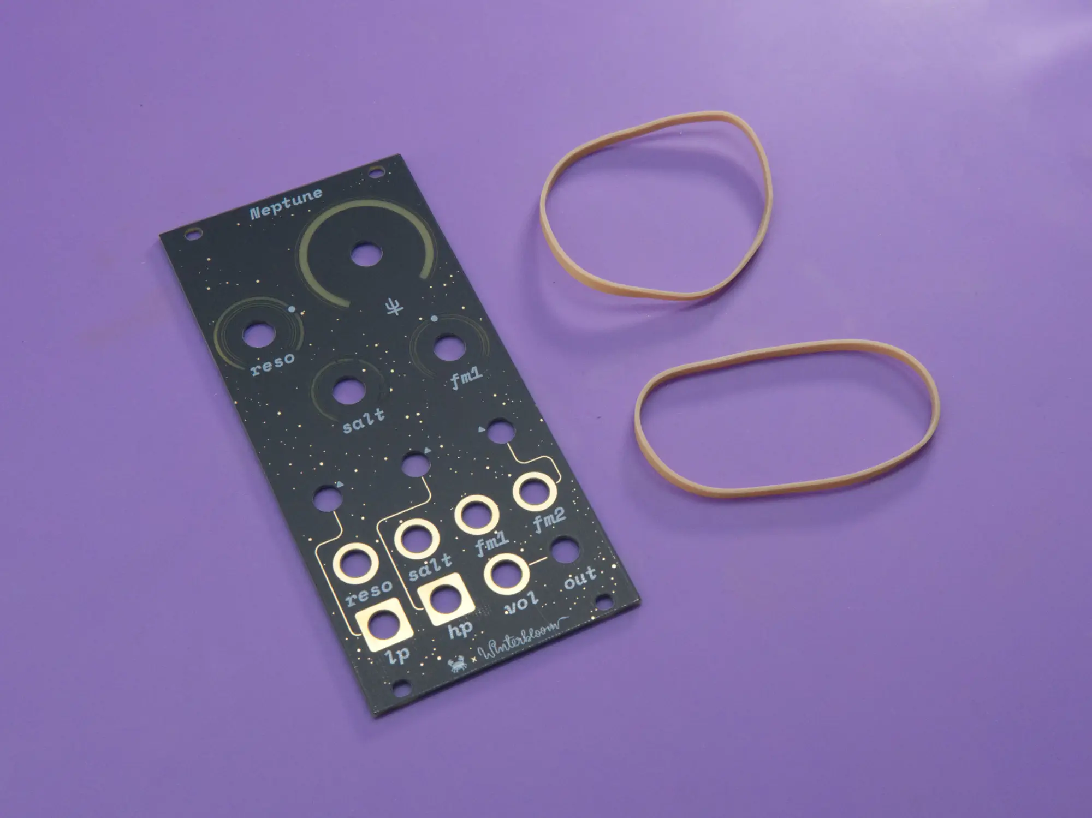
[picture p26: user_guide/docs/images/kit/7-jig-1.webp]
  
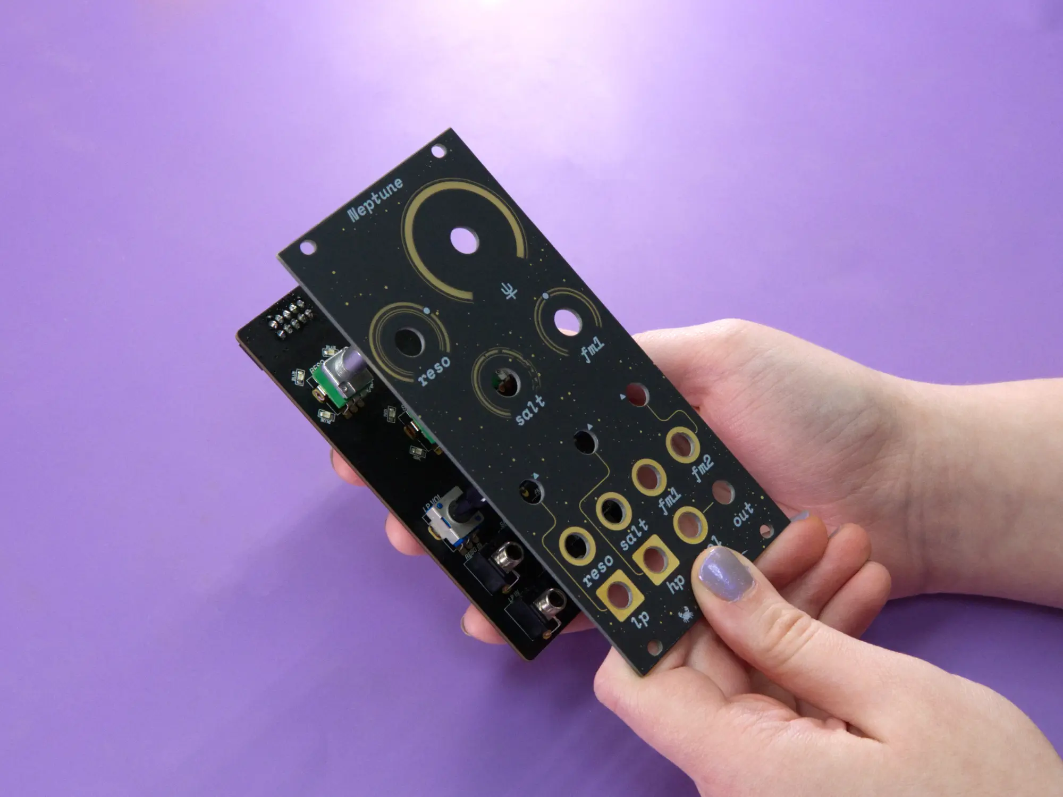
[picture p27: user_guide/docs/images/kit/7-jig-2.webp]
  
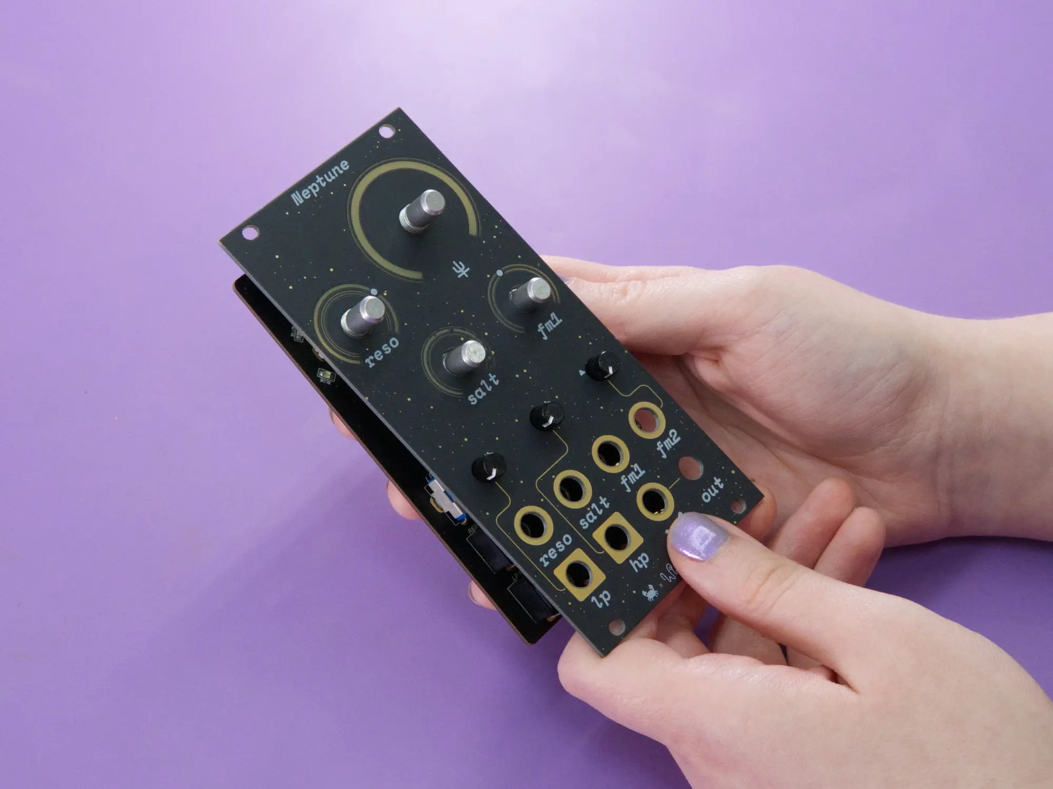
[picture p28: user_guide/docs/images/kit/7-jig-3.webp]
  
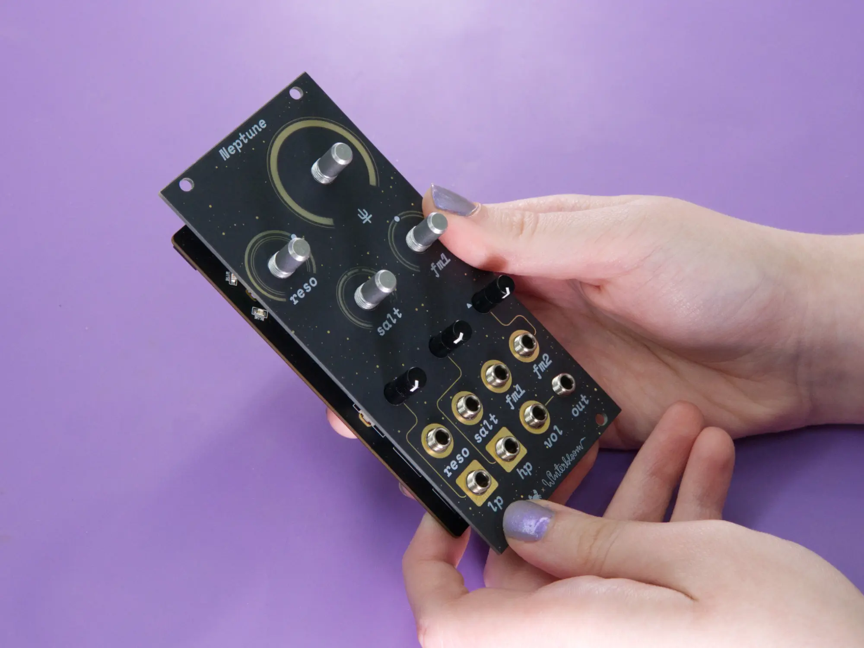
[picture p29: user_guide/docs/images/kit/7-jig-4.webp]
  
</winter-carousel>

Take a moment to check that everything is aligned and flush, as it's much easier to fix now than later! Take the first `rubber band` and wrap it *twice* around the upper part of the module. Try to keep it in the same spot as the picture, since it'll make your life a little easier in the next step.

<winter-carousel>
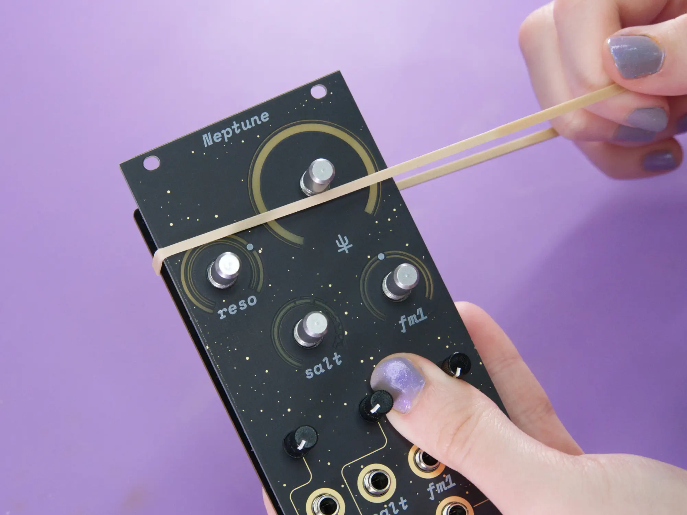
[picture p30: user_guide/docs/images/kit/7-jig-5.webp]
  
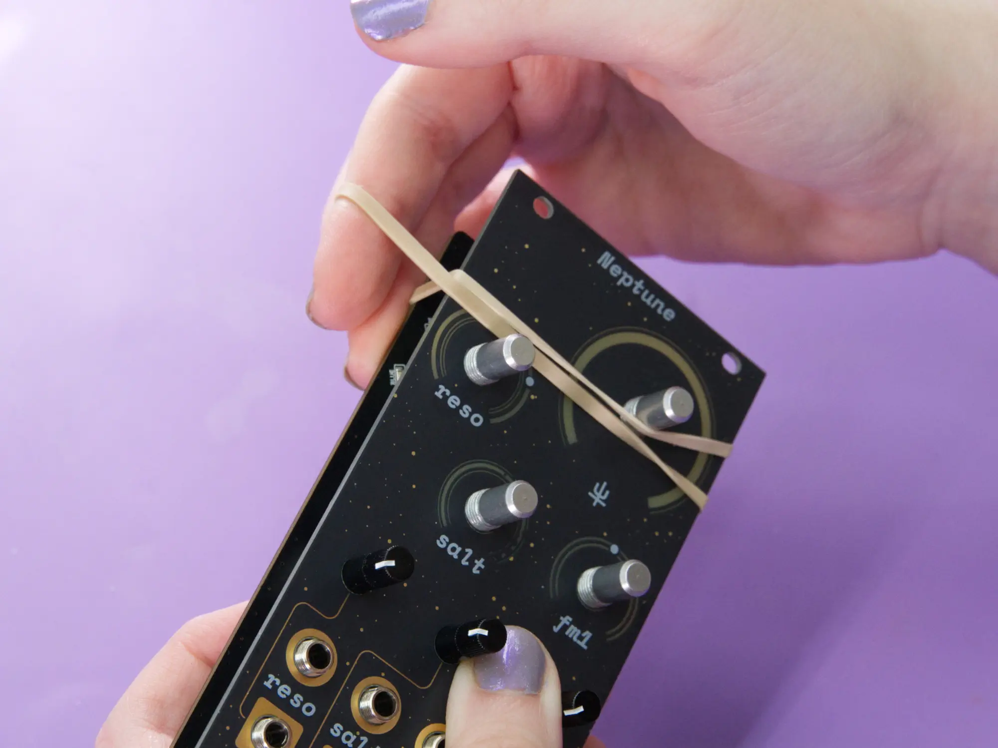
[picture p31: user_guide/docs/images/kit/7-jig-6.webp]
  
</winter-carousel>

Now take the second `rubber band` and wrap it *twice* around the lower part of the module, once again, try to keep it in the same spot shown.

<winter-carousel>
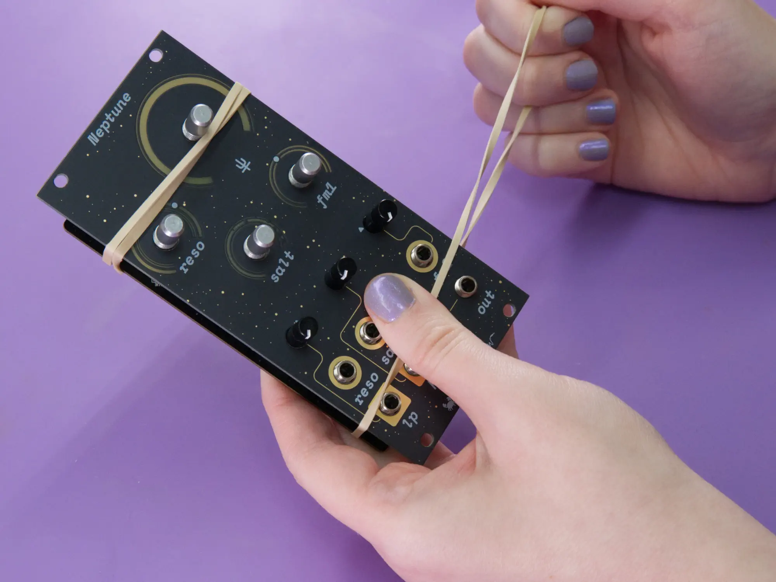
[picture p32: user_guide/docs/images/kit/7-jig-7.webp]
  
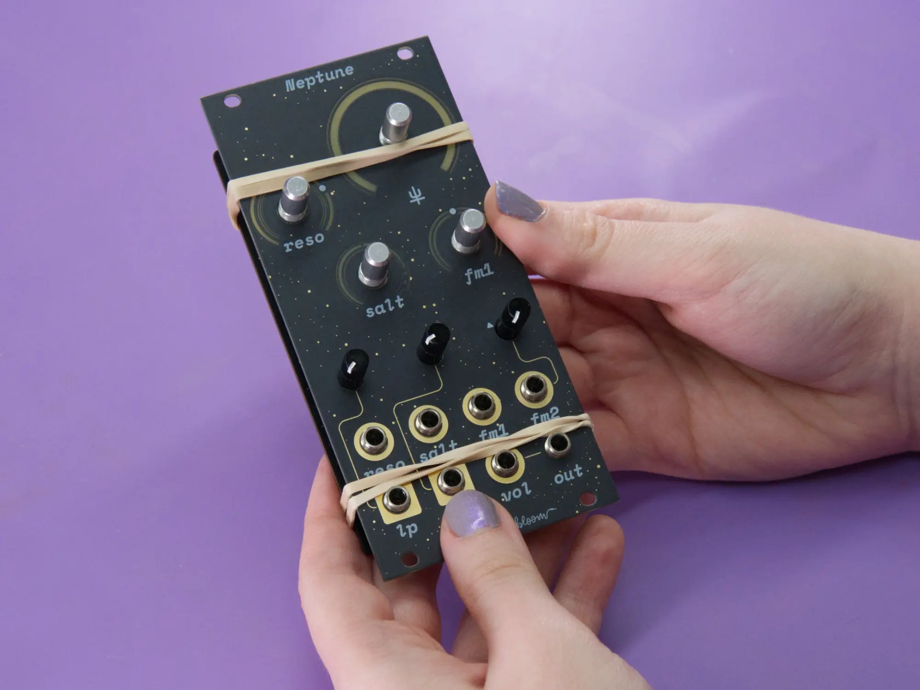
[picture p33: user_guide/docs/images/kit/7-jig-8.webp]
  
</winter-carousel>

Now that everything is held in place, flip the module over. Double check that all the components are aligned, flush, and that the pins are sticking through all the gold pads.

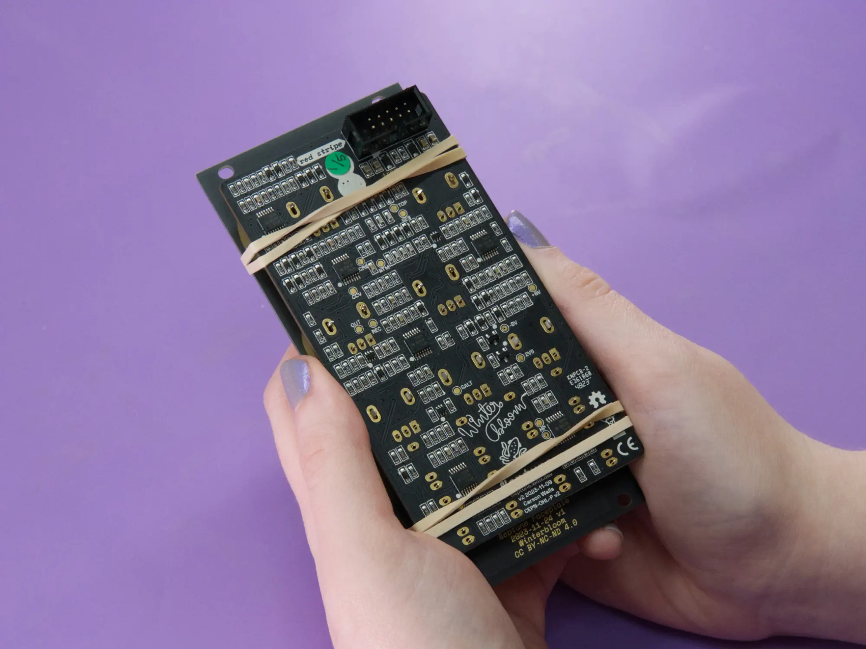
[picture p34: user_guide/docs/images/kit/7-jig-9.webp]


## First soldering pass

Now's the time to break out the soldering iron! Your next task is to solder the pots and jacks in place. While you can do all of the soldering in one pass, we recommend following this two pass approach since it gives you one last chance to double check everything before it becomes **much** harder to fix.

!!! warning "Look out below!"
    Be careful when soldering near Neptune's little surface mount components. Keep a close eye on your iron, as it's easy to accidentally angle it in a way that unintentionally hits one of the components.

Start by soldering just the **large, oval** pads for all of the pots:

<winter-carousel>
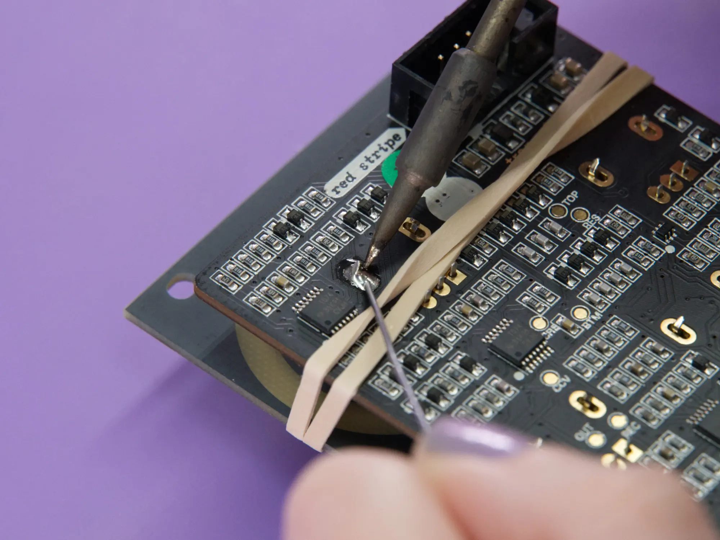
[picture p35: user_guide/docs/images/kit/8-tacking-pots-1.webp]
  
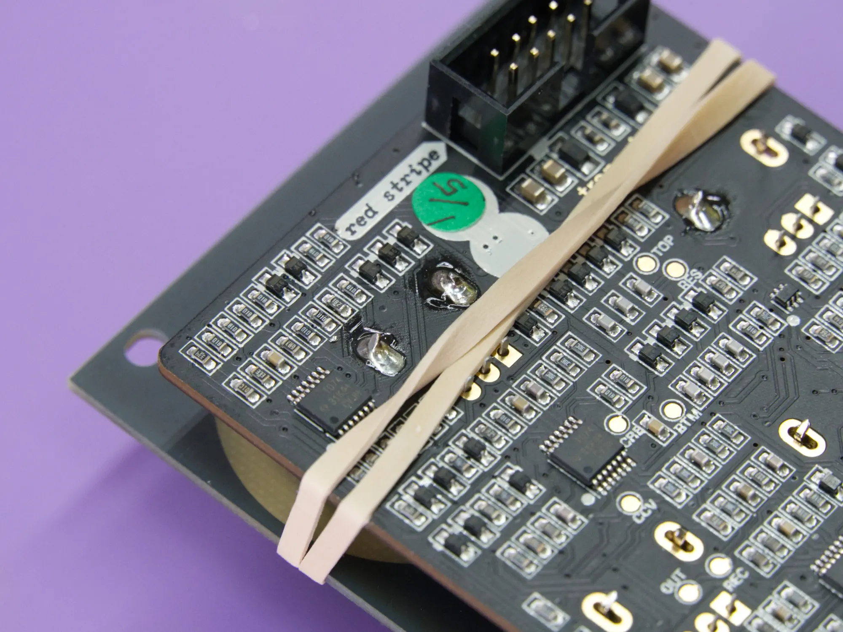
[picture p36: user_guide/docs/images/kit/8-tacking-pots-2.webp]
  
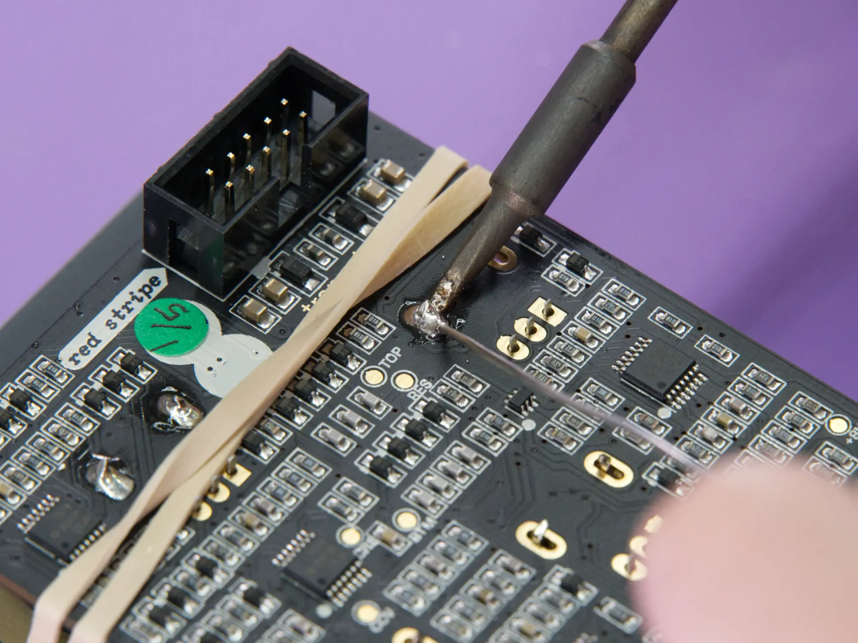
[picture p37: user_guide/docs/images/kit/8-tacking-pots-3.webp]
  
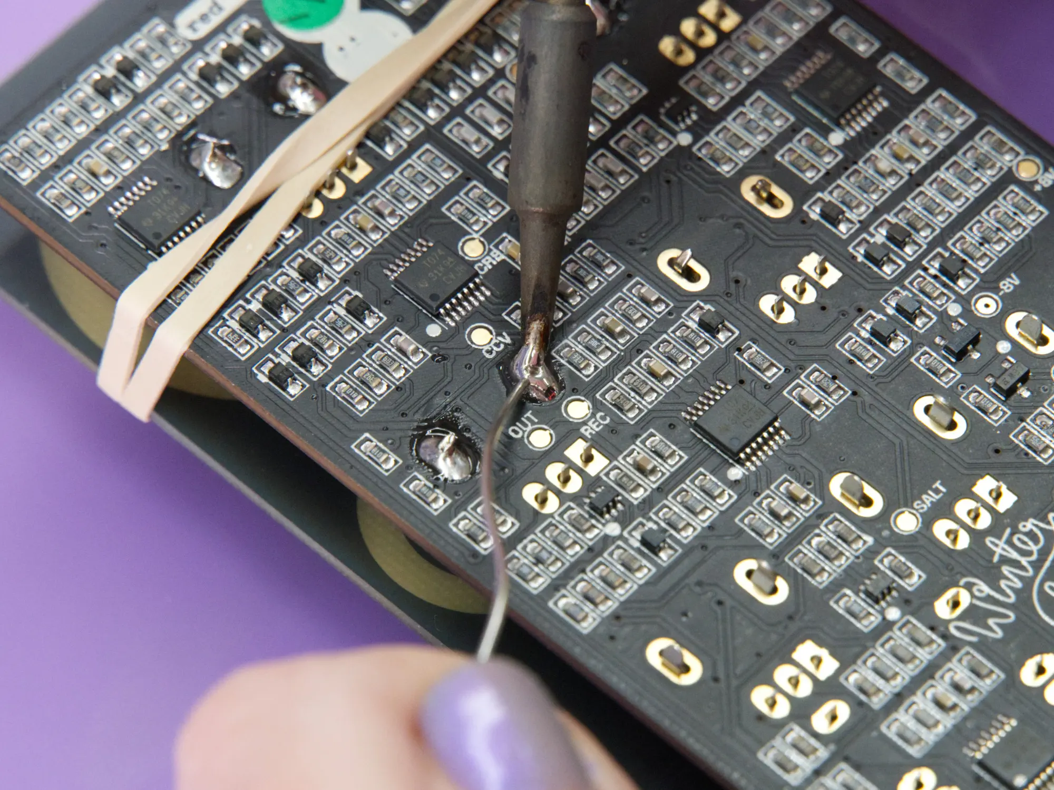
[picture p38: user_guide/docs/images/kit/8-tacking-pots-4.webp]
  
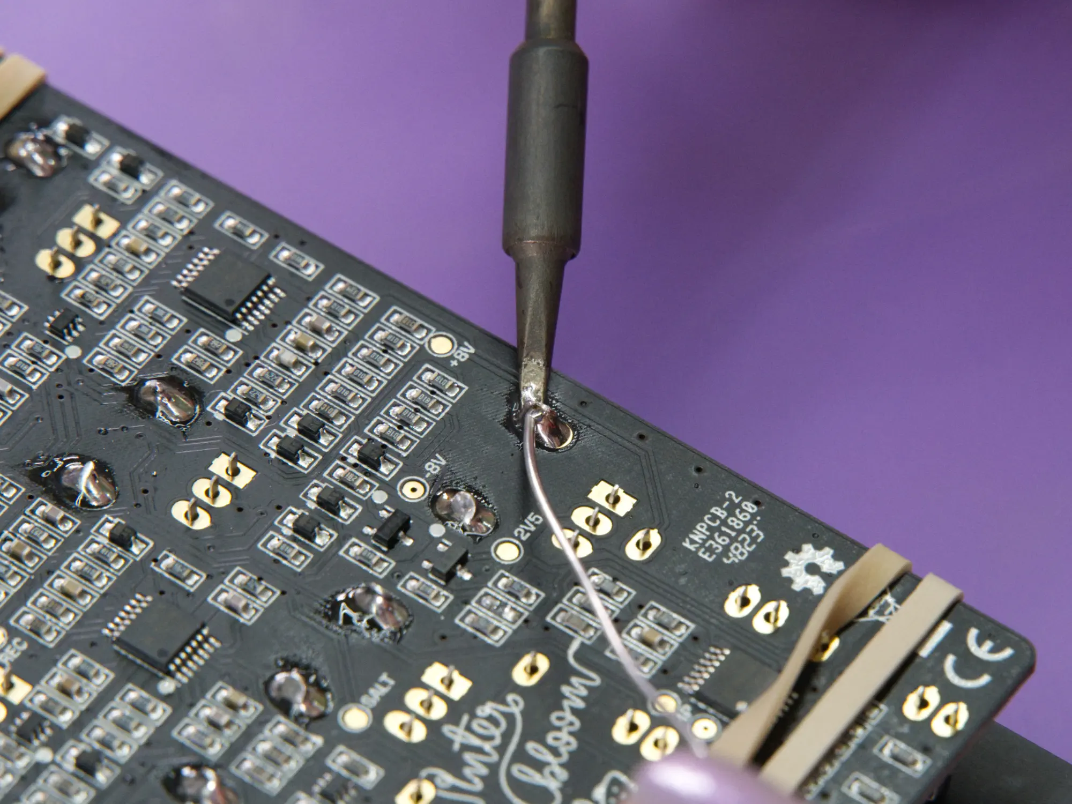
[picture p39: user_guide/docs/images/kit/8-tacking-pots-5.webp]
  
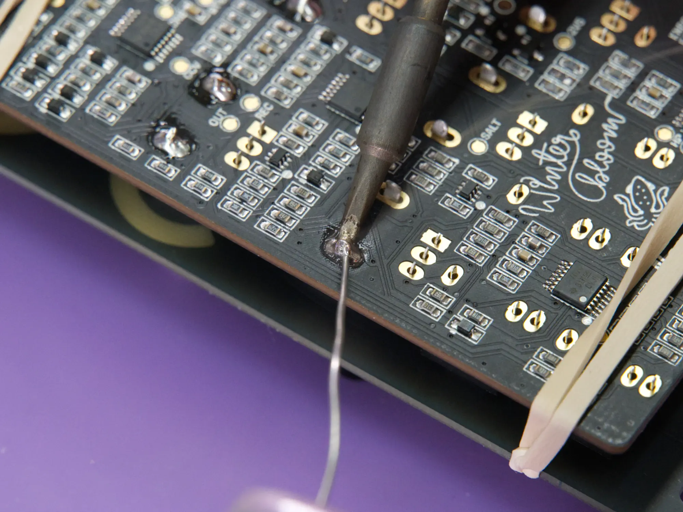
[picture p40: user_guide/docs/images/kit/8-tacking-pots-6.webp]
  
</winter-carousel>

Next, solder all the pins for the jacks that aren't obscured by the rubber band. You'll come back for the rest later.

<winter-carousel>
  
  
  
  
  
  
</winter-carousel>

Once done, your board should look like the image below:

Rubber banded

**Take this last chance to double-check your work**. If any of the jacks or pots aren't flush or if any of their little pins managed to bend and miss their holes, fix that now. Once you've completely soldered everything it'll be **much** harder to fix!

## Second soldering pass

With everything in place, you can remove the rubber bands and finish up soldering. Start by taking off the rubber bands and removing the faceplate:

<winter-carousel>
  
  
</winter-carousel>

Now you can go through and solder all of the remaining legs on the pots and jacks:

<winter-carousel>
  
  
  
  
</winter-carousel>

Once done, your board should look like the following pictures:

<winter-carousel>
  
  
</winter-carousel>

## Hardware

Your next task is to place the washers and nuts on the pots and jacks.

Hardware

!!! fairy "Dressing"
    Fun fact, we call this process "dressing"! It's like putting fancy clothes on your module. 🤵‍♀️

Start with the four `washers` for the 9mm pots, placing a single washer on each pot shaft:

<winter-carousel>
  
  
  
  
  
  
</winter-carousel>

Once the washers are in place, place the four larger `pot nuts` onto the pot shafts and hand tighten them.

<winter-carousel>
  
  
  
  
  
  
  
  
</winter-carousel>

Finally, place the eight smaller `jack nuts` onto each jack and hand tighten them:

<winter-carousel>
  
  
  
  
  
</winter-carousel>

Once done, your module should look like the image below.

Hardware done

## Knobs

Your final task is to add the four knobs to the 9mm pots.

Knobs

Start by loosening the set screw on each of the knobs using a small flat head screwdriver.

<winter-carousel>
  
  
</winter-carousel>

Next, turn all of the 9mm pots fully counterclockwise. Place the `large knob` on the top right shaft with the indicator line at the **7 o' clock** position. Tighten the set screw to secure the knob in place.

<winter-carousel>
  
  
</winter-carousel>

Do the same for the remaining three `small knobs`.

<winter-carousel>
  
  
  
</winter-carousel>

## Finished

Congrats, you finished building your very own Neptune!

Completed module

Don't forget to go check out the [User's Guide](/). We'd love to see your work, feel free to tag us on social media - we're `@wntrblm` on both [Twitter] and [Instagram].

If you have any feedback or ran into any issues, feel free to drop us an email at support@winterbloom.com or file a issue on [GitHub].

[Twitter]: https://twitter.com/wntrblm
[Instagram]: https://instagram.com/wntrblm
[GitHub]: https://github.com/wntrblm/Neptune

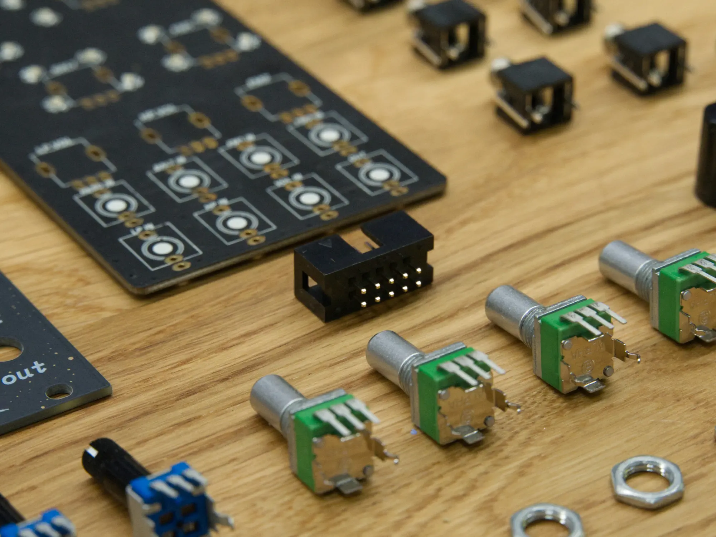
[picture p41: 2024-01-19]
user_guide/docs/images/kit/0-knolled.webp

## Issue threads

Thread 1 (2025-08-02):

ibom for hand-solderers

extremenerble, 2025-08-02:
For those who want to hand solder instead of PCBA, I created an ibom from the KiCad file since the silkscreen does not have part reference markers.

Good luck!

[ibom.html.zip](https://github.com/user-attachments/files/21556820/ibom.html.zip)

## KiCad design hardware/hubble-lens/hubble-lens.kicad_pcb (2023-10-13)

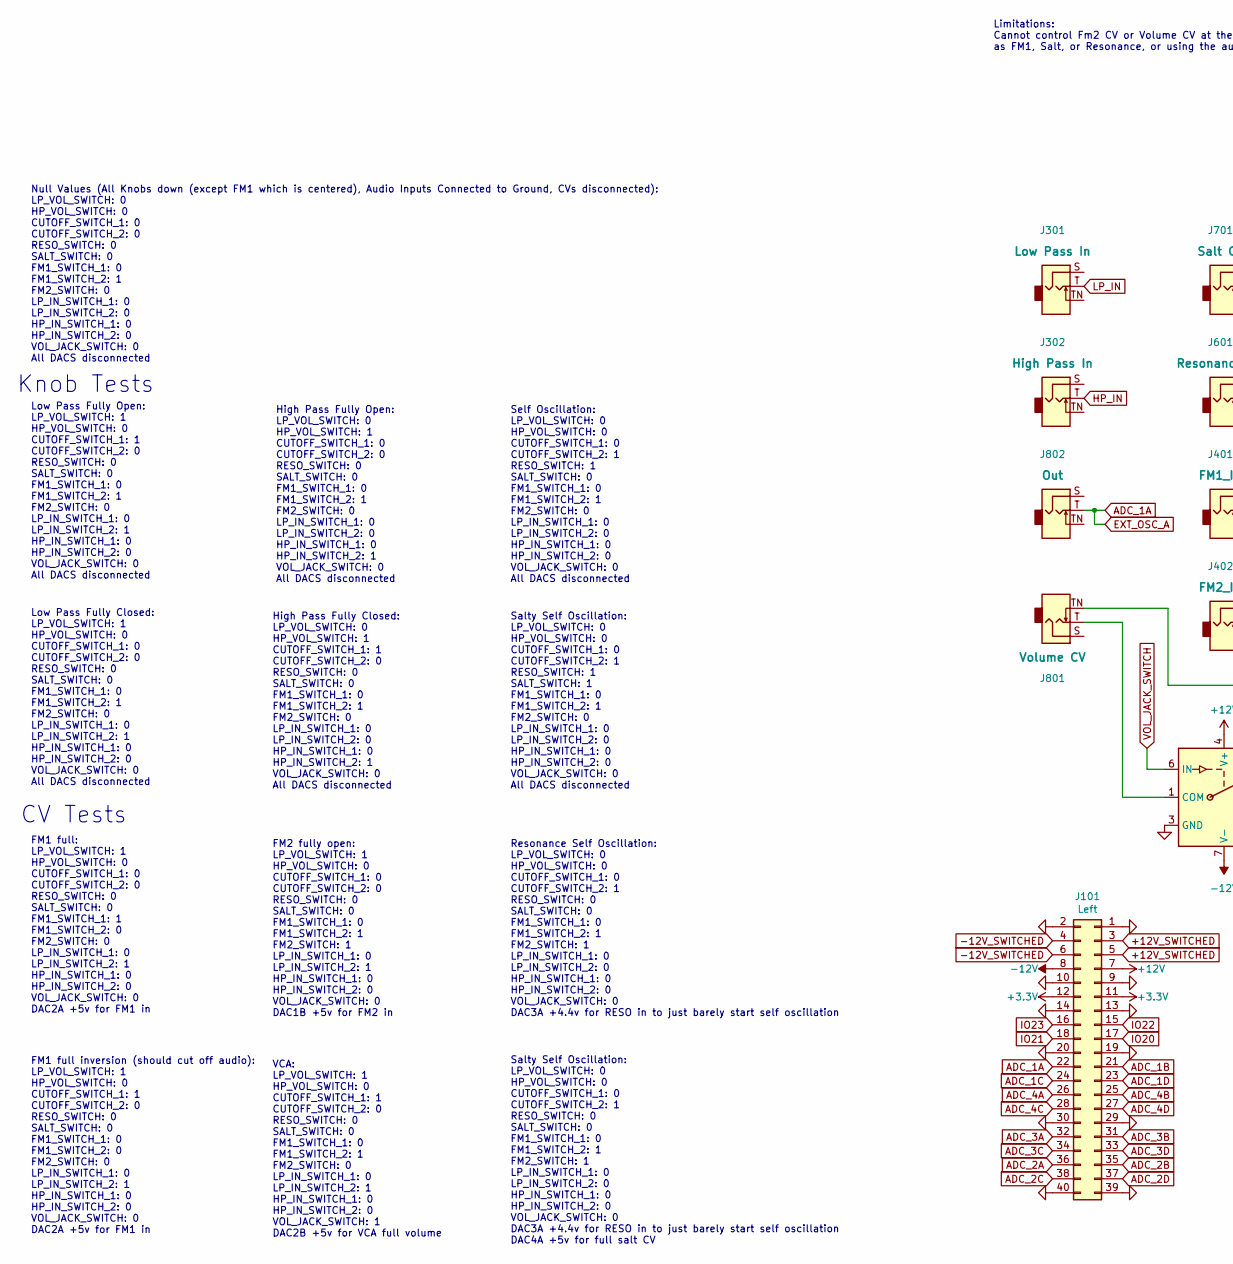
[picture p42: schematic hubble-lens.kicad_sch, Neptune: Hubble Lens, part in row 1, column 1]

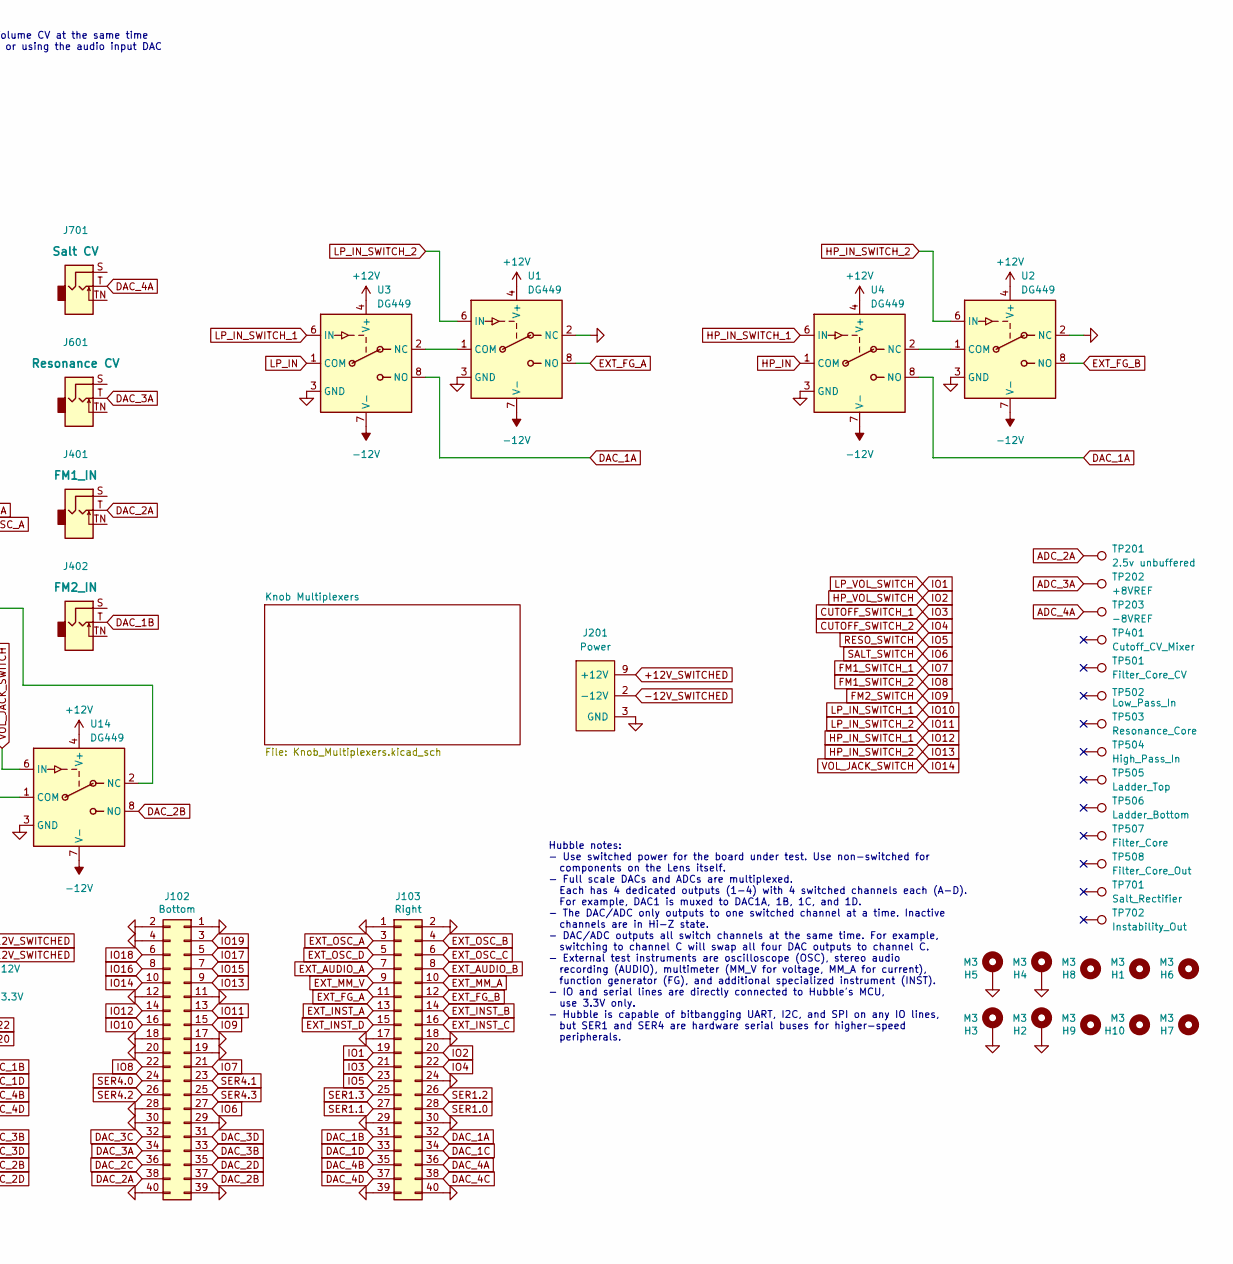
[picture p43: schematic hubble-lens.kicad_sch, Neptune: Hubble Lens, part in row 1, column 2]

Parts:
H1, H6, H7, H8, H9, H10: M3; MountingHole_3.2mm_M3
H2, H3, H4, H5: M3; MountingHole_3.2mm_M3_Pad_Via
J101: Left; PinSocket_2x20_P2.54mm_Vertical
J102: Bottom; PinSocket_2x20_P2.54mm_Vertical
J103: Right; PinSocket_2x20_P2.54mm_Vertical
J201: Power; Eurorack_Power_2x5_Shrouded_Lock; MPN 302-S101
J301, J302, J401, J402, J601, J701, J801, J802: AudioJack_WQP518MA_Compact_S; MPN WQP-WQP518MA
TP201, TP202, TP203, TP401, TP501, TP502, TP503, TP504, TP505, TP506, TP507, TP508, TP701, TP702: TestPoint_THTPad_D2.0mm_Drill1.0mm
U1, U2, U3, U4, U14: DG449; Vishay_SOT-23_8

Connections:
+3V3: J101.11, J101.12
+12V: J101.7, U1.4 (V+), U2.4 (V+), U3.4 (V+), U4.4 (V+), U14.4 (V+); also elsewhere on the board
+12V_SWITCHED: J101.3, J101.5, J201.9 (+12V), J201.10 (+12V)
-12V: J101.8, U1.7 (V-), U2.7 (V-), U3.7 (V-), U4.7 (V-), U14.7 (V-); also elsewhere on the board
-12V_SWITCHED: J101.4, J101.6, J201.1 (-12V), J201.2 (-12V)
ADC_1A: J101.22, J103.3, J802.T (Tip)
ADC_1B: J101.21
ADC_1C: J101.24
ADC_1D: J101.23
ADC_2A: J101.36, TP201.1
ADC_2B: J101.35
ADC_2C: J101.38
ADC_2D: J101.37
ADC_3A: J101.32, TP202.1
ADC_3B: J101.31
ADC_3C: J101.34
ADC_3D: J101.33
ADC_4A: J101.26, TP203.1
ADC_4B: J101.25
ADC_4C: J101.28
ADC_4D: J101.27
CUTOFF_SWITCH_1: J103.21; also elsewhere on the board
CUTOFF_SWITCH_2: J103.22; also elsewhere on the board
DAC_1A: J103.32, U3.8 (NO), U4.8 (NO)
DAC_1B: J103.31, J402.T (Tip)
DAC_1C: J103.34
DAC_1D: J103.33
DAC_2A: J102.38, J401.T (Tip)
DAC_2B: J102.37, U14.8 (NO)
DAC_2C: J102.36
DAC_2D: J102.35
DAC_3A: J102.34, J601.T (Tip)
DAC_3B: J102.33
DAC_3C: J102.32
DAC_3D: J102.31
DAC_4A: J103.36, J701.T (Tip)
DAC_4B: J103.35
DAC_4C: J103.38
DAC_4D: J103.37
EXT_AUDIO_A: J103.7
EXT_AUDIO_B: J103.8
EXT_FG_A: J103.11, U1.8 (NO)
EXT_FG_B: J103.12, U2.8 (NO)
EXT_INST_A: J103.13
EXT_INST_B: J103.14
EXT_INST_C: J103.16
EXT_INST_D: J103.15
EXT_MM_A: J103.10
EXT_MM_V: J103.9
EXT_OSC_B: J103.4
EXT_OSC_C: J103.6
EXT_OSC_D: J103.5
FM1_SWITCH_1: J102.21; also elsewhere on the board
FM1_SWITCH_2: J102.22; also elsewhere on the board
FM2_SWITCH: J102.15; also elsewhere on the board
GND: H2.1, H3.1, H4.1, H5.1, J101.1, J101.2, J101.9, J101.10, J101.13, J101.14, J101.19, J101.20, J101.29, J101.30, J101.39, J101.40, J102.1, J102.2, J102.4, J102.11, J102.12, J102.17, J102.18, J102.19, J102.20, J102.28, J102.29, J102.30, J102.39, J102.40, J103.1, J103.2, J103.17, J103.18, J103.24, J103.29, J103.30, J103.39, J103.40, J201.3 (GND), J201.4 (GND), J201.5 (GND), J201.6 (GND), J201.7 (GND), J201.8 (GND), U1.2 (NC), U1.3 (GND), U2.2 (NC), U2.3 (GND), U3.3 (GND), U4.3 (GND), U14.3 (GND); also elsewhere on the board
HP_IN: J302.T (Tip), U4.1 (COM)
HP_IN_SWITCH_1: J102.14, U4.6 (IN)
HP_IN_SWITCH_2: J102.9, U2.6 (IN)
HP_VOL_SWITCH: J103.20; also elsewhere on the board
IO1: J103.19; also elsewhere on the board
IO5: J103.23; also elsewhere on the board
IO6: J102.27; also elsewhere on the board
IO10: J102.16, U3.6 (IN)
IO11: J102.13, U1.6 (IN)
IO14: J102.10, U14.6 (IN)
IO15: J102.7
IO16: J102.8
IO17: J102.5
IO18: J102.6
IO19: J102.3
IO20: J101.17
IO21: J101.18
IO22: J101.15
IO23: J101.16
LP_IN: J301.T (Tip), U3.1 (COM)
unnamed: J801.T (Tip), U14.1 (COM)
unnamed: J801.TN (Tip_normalize), U14.2 (NC)
unnamed: U1.1 (COM), U3.2 (NC)
unnamed: U2.1 (COM), U4.2 (NC)
SER1.0: J103.28
SER1.1: J103.27
SER1.2: J103.26
SER1.3: J103.25
SER4.0: J102.24
SER4.1: J102.23
SER4.2: J102.26
SER4.3: J102.25

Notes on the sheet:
Null Values (All Knobs down (except FM1 which is centered), Audio Inputs Connected to Ground, CVs disconnected): LP_VOL_SWITCH: 0 HP_VOL_SWITCH: 0 CUTOFF_SWITCH_1: 0 CUTOFF_SWITCH_2: 0 RESO_SWITCH: 0 SALT_SWITCH: 0 FM1_SWITCH_1: 0 FM1_SWITCH_2: 1 FM2_SWITCH: 0 LP_IN_SWITCH_1: 0 LP_IN_SWITCH_2: 0 HP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
Self Oscillation: LP_VOL_SWITCH: 0 HP_VOL_SWITCH: 0 CUTOFF_SWITCH_1: 0 CUTOFF_SWITCH_2: 1 RESO_SWITCH: 1 SALT_SWITCH: 0 FM1_SWITCH_1: 0 FM1_SWITCH_2: 1 FM2_SWITCH: 0 LP_IN_SWITCH_1: 0 LP_IN_SWITCH_2: 0 HP_IN_SWITCH_1: 0 HP_IN_SWITCH_2: 0 VOL_JACK_SWITCH: 0 All DACS disconnected
Knob Tests
Limitations: Cannot control Fm2 CV or Volume CV at the same time as FM1, Salt, or Resonance, or using the audio input DAC
VCA: LP_VOL_SWITCH: 1 HP_VOL_SWITCH: 0 CUTOFF_SWITCH_1: 1 CUTOFF_SWITCH_2: 0 RESO_SWITCH: 0 SALT_SWITCH: 0 FM1_SWITCH_1: 0 FM1_SWITCH_2: 1 FM2_SWITCH: 0 LP_IN_SWITCH_1: 0 LP_IN_SWITCH_2: 1 HP_IN_SWITCH_1: 0 HP_IN_SWITCH_2: 0 VOL_JACK_SWITCH: 1 DAC2B +5v for VCA full volume
CV Tests
Salty Self Oscillation: LP_VOL_SWITCH: 0 HP_VOL_SWITCH: 0 CUTOFF_SWITCH_1: 0 CUTOFF_SWITCH_2: 1 RESO_SWITCH: 0 SALT_SWITCH: 0 FM1_SWITCH_1: 0 FM1_SWITCH_2: 1 FM2_SWITCH: 1 LP_IN_SWITCH_1: 0 LP_IN_SWITCH_2: 0 HP_IN_SWITCH_1: 0 HP_IN_SWITCH_2: 0 VOL_JACK_SWITCH: 0 DAC3A +4.4v for RESO in to just bare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
High Pass Fully Closed: LP_VOL_SWITCH: 0 HP_VOL_SWITCH: 1 CUTOFF_SWITCH_1: 1 CUTOFF_SWITCH_2: 0 RESO_SWITCH: 0 SALT_SWITCH: 0 FM1_SWITCH_1: 0 FM1_SWITCH_2: 1 FM2_SWITCH: 0 LP_IN_SWITCH_1: 0 LP_IN_SWITCH_2: 0 HP_IN_SWITCH_1: 0 HP_IN_SWITCH_2: 1 VOL_JACK_SWITCH: 0 All DACS disconnected
FM1 full inversion (should cut off audio): LP_VOL_SWITCH: 1 HP_VOL_SWITCH: 0 CUTOFF_SWITCH_1: 1 CUTOFF_SWITCH_2: 0 RESO_SWITCH: 0 SALT_SWITCH: 0 FM1_SWITCH_1: 0 FM1_SWITCH_2: 0 FM2_SWITCH: 0 LP_IN_SWITCH_1: 0 LP_IN_SWITCH_2: 1 HP_IN_SWITCH_1: 0 HP_IN_SWITCH_2: 0 VOL_JACK_SWITCH: 0 DAC2A +5v for FM1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
Hubble notes: - Use switched power for the board under test. Use non-switched for components on the Lens itself. - Full scale DACs and ADCs are multiplexed. Each has 4 dedicated outputs (1-4) with 4 switched channels each (A-D). For example, DAC1 is muxed to DAC1A, 1B, 1C, and 1D. - The DAC/ADC onl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
FM2 fully open: LP_VOL_SWITCH: 1 HP_VOL_SWITCH: 0 CUTOFF_SWITCH_1: 0 CUTOFF_SWITCH_2: 0 RESO_SWITCH: 0 SALT_SWITCH: 0 FM1_SWITCH_1: 0 FM1_SWITCH_2: 1 FM2_SWITCH: 1 LP_IN_SWITCH_1: 0 LP_IN_SWITCH_2: 1 HP_IN_SWITCH_1: 0 HP_IN_SWITCH_2: 0 VOL_JACK_SWITCH: 0 DAC1B +5v for FM2 in
Low Pass Fully Closed: LP_VOL_SWITCH: 1 HP_VOL_SWITCH: 0 CUTOFF_SWITCH_1: 0 CUTOFF_SWITCH_2: 0 RESO_SWITCH: 0 SALT_SWITCH: 0 FM1_SWITCH_1: 0 FM1_SWITCH_2: 1 FM2_SWITCH: 0 LP_IN_SWITCH_1: 0 LP_IN_SWITCH_2: 1 HP_IN_SWITCH_1: 0 HP_IN_SWITCH_2: 0 VOL_JACK_SWITCH: 0 All DACS disconnected
FM1 full: LP_VOL_SWITCH: 1 HP_VOL_SWITCH: 0 CUTOFF_SWITCH_1: 0 CUTOFF_SWITCH_2: 0 RESO_SWITCH: 0 SALT_SWITCH: 0 FM1_SWITCH_1: 1 FM1_SWITCH_2: 0 FM2_SWITCH: 0 LP_IN_SWITCH_1: 0 LP_IN_SWITCH_2: 1 HP_IN_SWITCH_1: 0 HP_IN_SWITCH_2: 0 VOL_JACK_SWITCH: 0 DAC2A +5v for FM1 in
Low Pass Fully Open: LP_VOL_SWITCH: 1 HP_VOL_SWITCH: 0 CUTOFF_SWITCH_1: 1 CUTOFF_SWITCH_2: 0 RESO_SWITCH: 0 SALT_SWITCH: 0 FM1_SWITCH_1: 0 FM1_SWITCH_2: 1 FM2_SWITCH: 0 LP_IN_SWITCH_1: 0 LP_IN_SWITCH_2: 1 HP_IN_SWITCH_1: 0 HP_IN_SWITCH_2: 0 VOL_JACK_SWITCH: 0 All DACS disconnected
Salty Self Oscillation: LP_VOL_SWITCH: 0 HP_VOL_SWITCH: 0 CUTOFF_SWITCH_1: 0 CUTOFF_SWITCH_2: 1 RESO_SWITCH: 1 SALT_SWITCH: 1 FM1_SWITCH_1: 0 FM1_SWITCH_2: 1 FM2_SWITCH: 0 LP_IN_SWITCH_1: 0 LP_IN_SWITCH_2: 0 HP_IN_SWITCH_1: 0 HP_IN_SWITCH_2: 0 VOL_JACK_SWITCH: 0 All DACS disconnected
High Pass Fully Open: LP_VOL_SWITCH: 0 HP_VOL_SWITCH: 1 CUTOFF_SWITCH_1: 0 CUTOFF_SWITCH_2: 0 RESO_SWITCH: 0 SALT_SWITCH: 0 FM1_SWITCH_1: 0 FM1_SWITCH_2: 1 FM2_SWITCH: 0 LP_IN_SWITCH_1: 0 LP_IN_SWITCH_2: 0 HP_IN_SWITCH_1: 0 HP_IN_SWITCH_2: 1 VOL_JACK_SWITCH: 0 All DACS disconnected
Resonance Self Oscillation: LP_VOL_SWITCH: 0 HP_VOL_SWITCH: 0 CUTOFF_SWITCH_1: 0 CUTOFF_SWITCH_2: 1 RESO_SWITCH: 0 SALT_SWITCH: 0 FM1_SWITCH_1: 0 FM1_SWITCH_2: 1 FM2_SWITCH: 1 LP_IN_SWITCH_1: 0 LP_IN_SWITCH_2: 0 HP_IN_SWITCH_1: 0 HP_IN_SWITCH_2: 0 VOL_JACK_SWITCH: 0 DAC3A +4.4v for RESO in to just 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

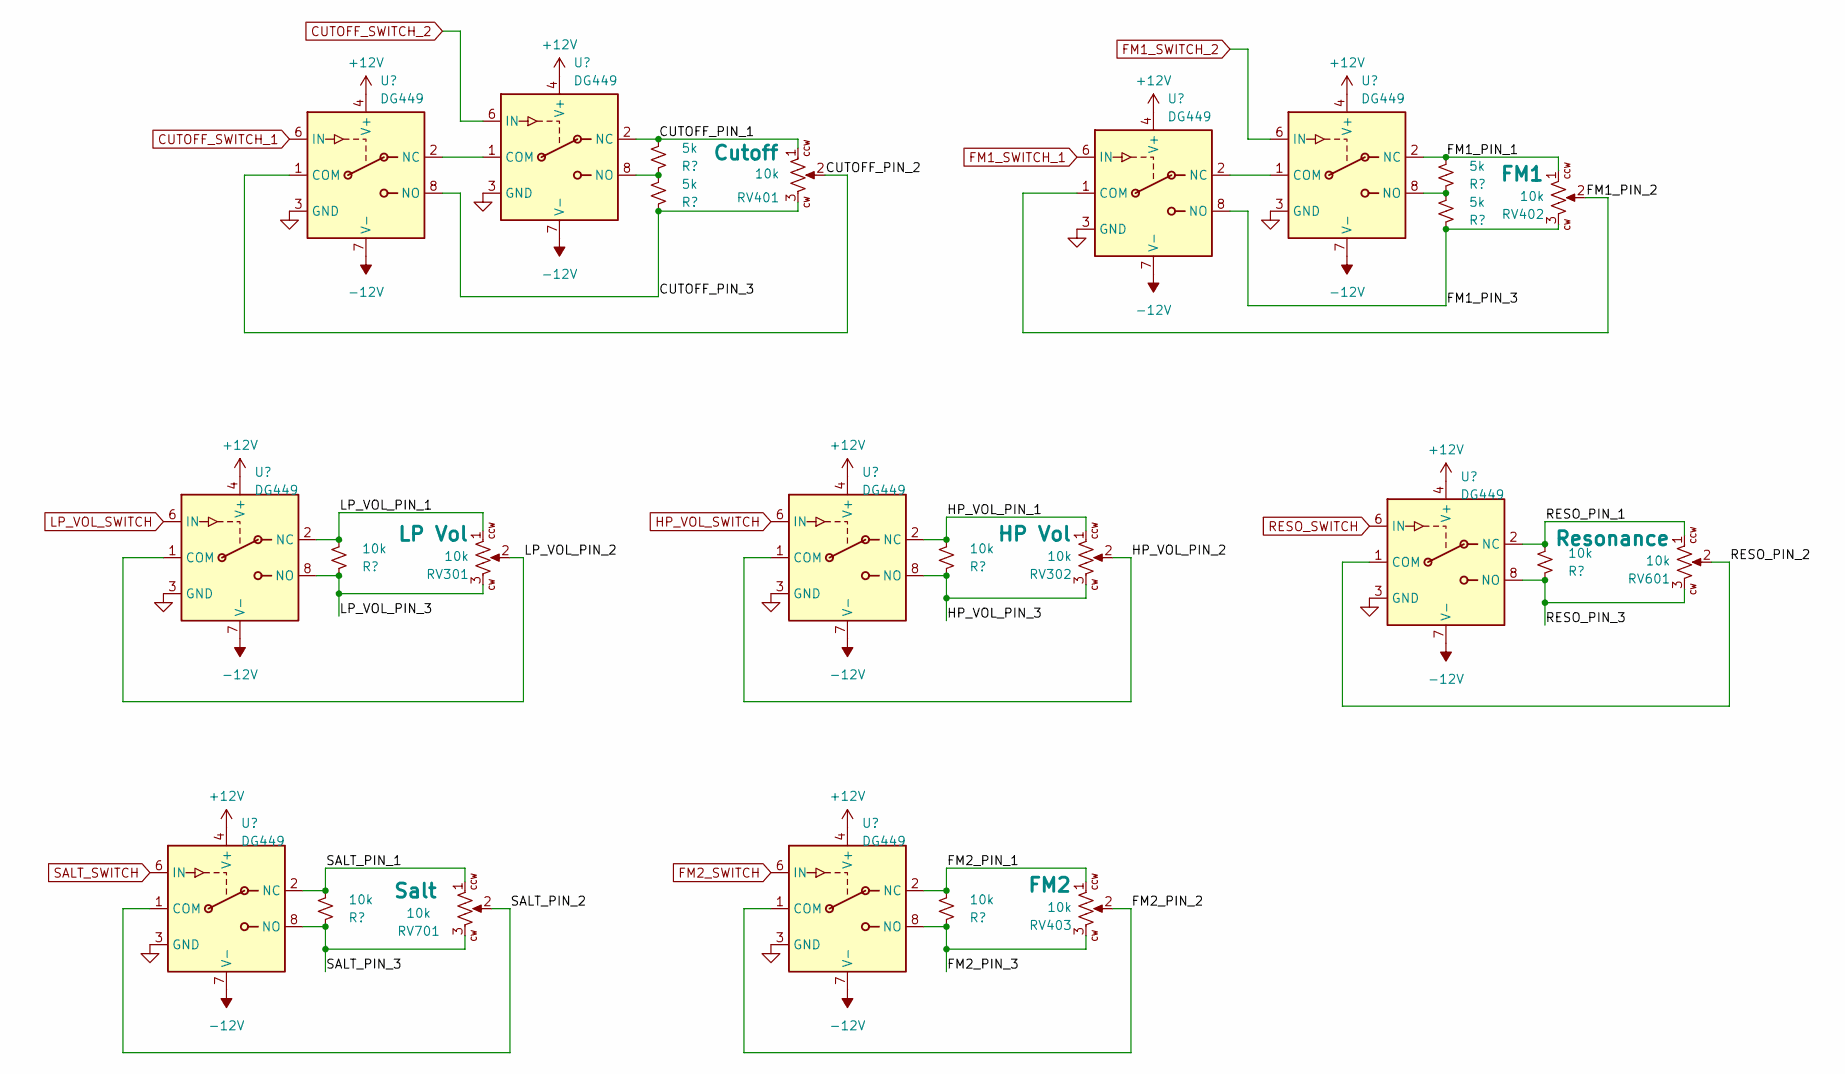
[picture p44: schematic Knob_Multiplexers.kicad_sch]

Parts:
R1, R2, R3, R4: 5k; R_0603_HandSolder
R5, R6, R7, R8, R9: 10k; R_0603_HandSolder
RV301, RV302, RV401, RV402, RV403, RV601, RV701: 10k; Potentiometer_Alpha_R0904N; Rating B10k
U5, U6, U7, U8, U9, U10, U11, U12, U13: DG449; Vishay_SOT-23_8

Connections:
+12V: U5.4 (V+), U6.4 (V+), U7.4 (V+), U8.4 (V+), U9.4 (V+), U10.4 (V+), U11.4 (V+), U12.4 (V+), U13.4 (V+); also elsewhere on the board
-12V: U5.7 (V-), U6.7 (V-), U7.7 (V-), U8.7 (V-), U9.7 (V-), U10.7 (V-), U11.7 (V-), U12.7 (V-), U13.7 (V-); also elsewhere on the board
/Knob Multiplexers/CUTOFF_PIN_1: R1.2, RV401.1, U5.2 (NC)
/Knob Multiplexers/CUTOFF_PIN_2: RV401.2, U6.1 (COM)
/Knob Multiplexers/CUTOFF_PIN_3: R3.1, RV401.3, U6.8 (NO)
/Knob Multiplexers/FM1_PIN_1: R2.2, RV402.1, U7.2 (NC)
/Knob Multiplexers/FM1_PIN_2: RV402.2, U8.1 (COM)
/Knob Multiplexers/FM1_PIN_3: R4.1, RV402.3, U8.8 (NO)
/Knob Multiplexers/FM2_PIN_1: R9.2, RV403.1, U13.2 (NC)
/Knob Multiplexers/FM2_PIN_2: RV403.2, U13.1 (COM)
/Knob Multiplexers/FM2_PIN_3: R9.1, RV403.3, U13.8 (NO)
/Knob Multiplexers/HP_VOL_PIN_1: R6.2, RV302.1, U10.2 (NC)
/Knob Multiplexers/HP_VOL_PIN_2: RV302.2, U10.1 (COM)
/Knob Multiplexers/HP_VOL_PIN_3: R6.1, RV302.3, U10.8 (NO)
/Knob Multiplexers/LP_VOL_PIN_1: R5.2, RV301.1, U9.2 (NC)
/Knob Multiplexers/LP_VOL_PIN_2: RV301.2, U9.1 (COM)
/Knob Multiplexers/LP_VOL_PIN_3: R5.1, RV301.3, U9.8 (NO)
/Knob Multiplexers/RESO_PIN_1: R7.2, RV601.1, U11.2 (NC)
/Knob Multiplexers/RESO_PIN_2: RV601.2, U11.1 (COM)
/Knob Multiplexers/RESO_PIN_3: R7.1, RV601.3, U11.8 (NO)
/Knob Multiplexers/SALT_PIN_1: R8.2, RV701.1, U12.2 (NC)
/Knob Multiplexers/SALT_PIN_2: RV701.2, U12.1 (COM)
/Knob Multiplexers/SALT_PIN_3: R8.1, RV701.3, U12.8 (NO)
CUTOFF_SWITCH_1: U6.6 (IN); also elsewhere on the board
CUTOFF_SWITCH_2: U5.6 (IN); also elsewhere on the board
FM1_SWITCH_1: U8.6 (IN); also elsewhere on the board
FM1_SWITCH_2: U7.6 (IN); also elsewhere on the board
FM2_SWITCH: U13.6 (IN); also elsewhere on the board
GND: U5.3 (GND), U6.3 (GND), U7.3 (GND), U8.3 (GND), U9.3 (GND), U10.3 (GND), U11.3 (GND), U12.3 (GND), U13.3 (GND); also elsewhere on the board
HP_VOL_SWITCH: U10.6 (IN); also elsewhere on the board
IO1: U9.6 (IN); also elsewhere on the board
IO5: U11.6 (IN); also elsewhere on the board
IO6: U12.6 (IN); also elsewhere on the board
unnamed: U5.1 (COM), U6.2 (NC)
unnamed: R1.1, R3.2, U5.8 (NO)
unnamed: U7.1 (COM), U8.2 (NC)
unnamed: R2.1, R4.2, U7.8 (NO)

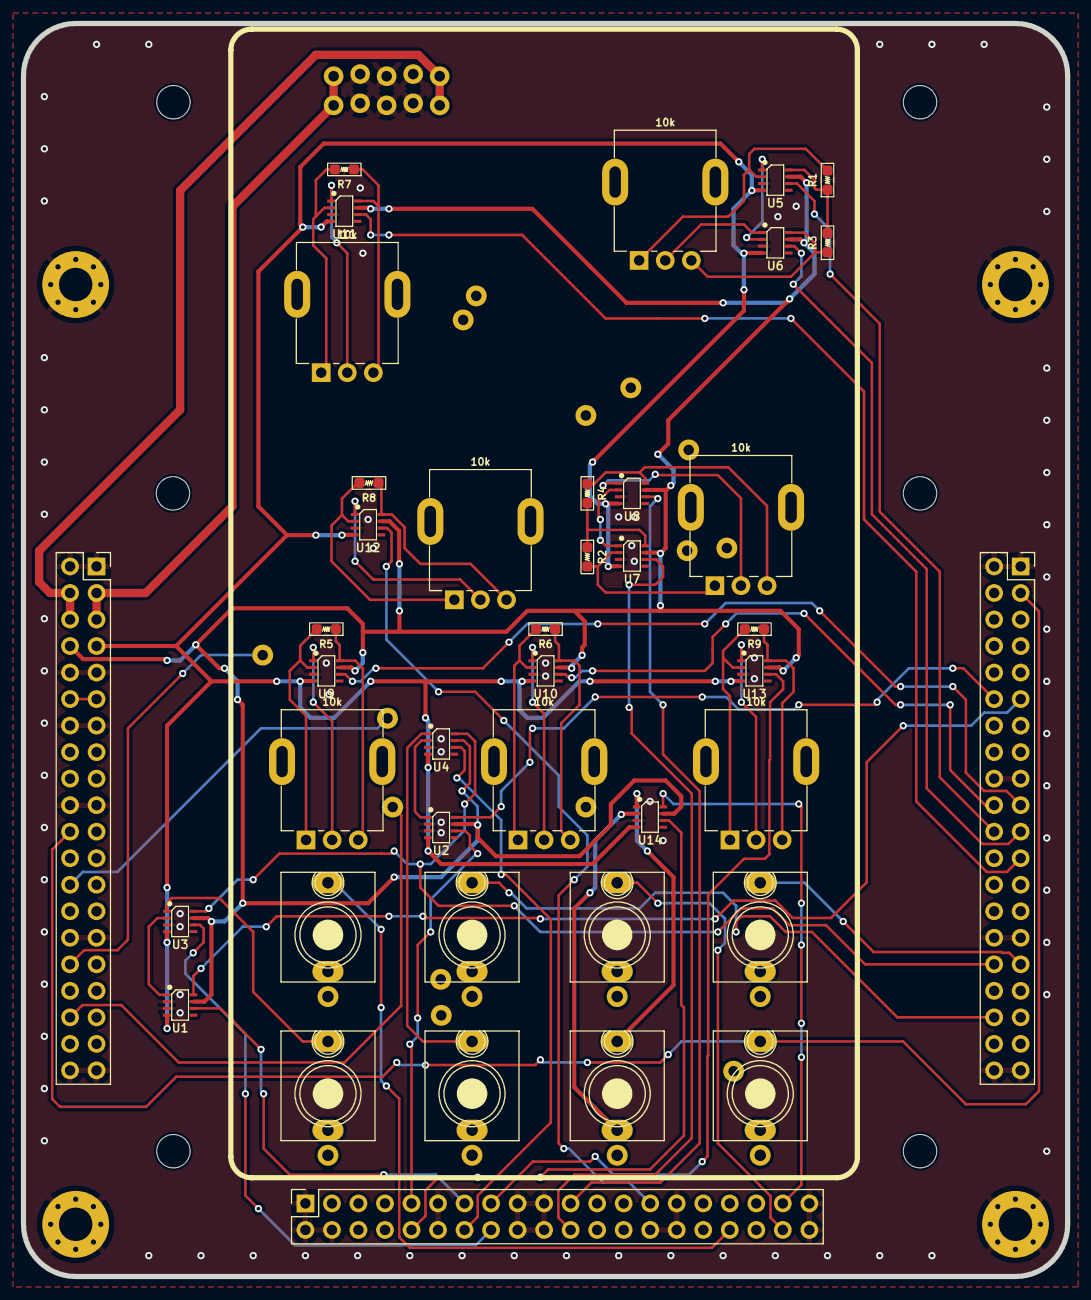
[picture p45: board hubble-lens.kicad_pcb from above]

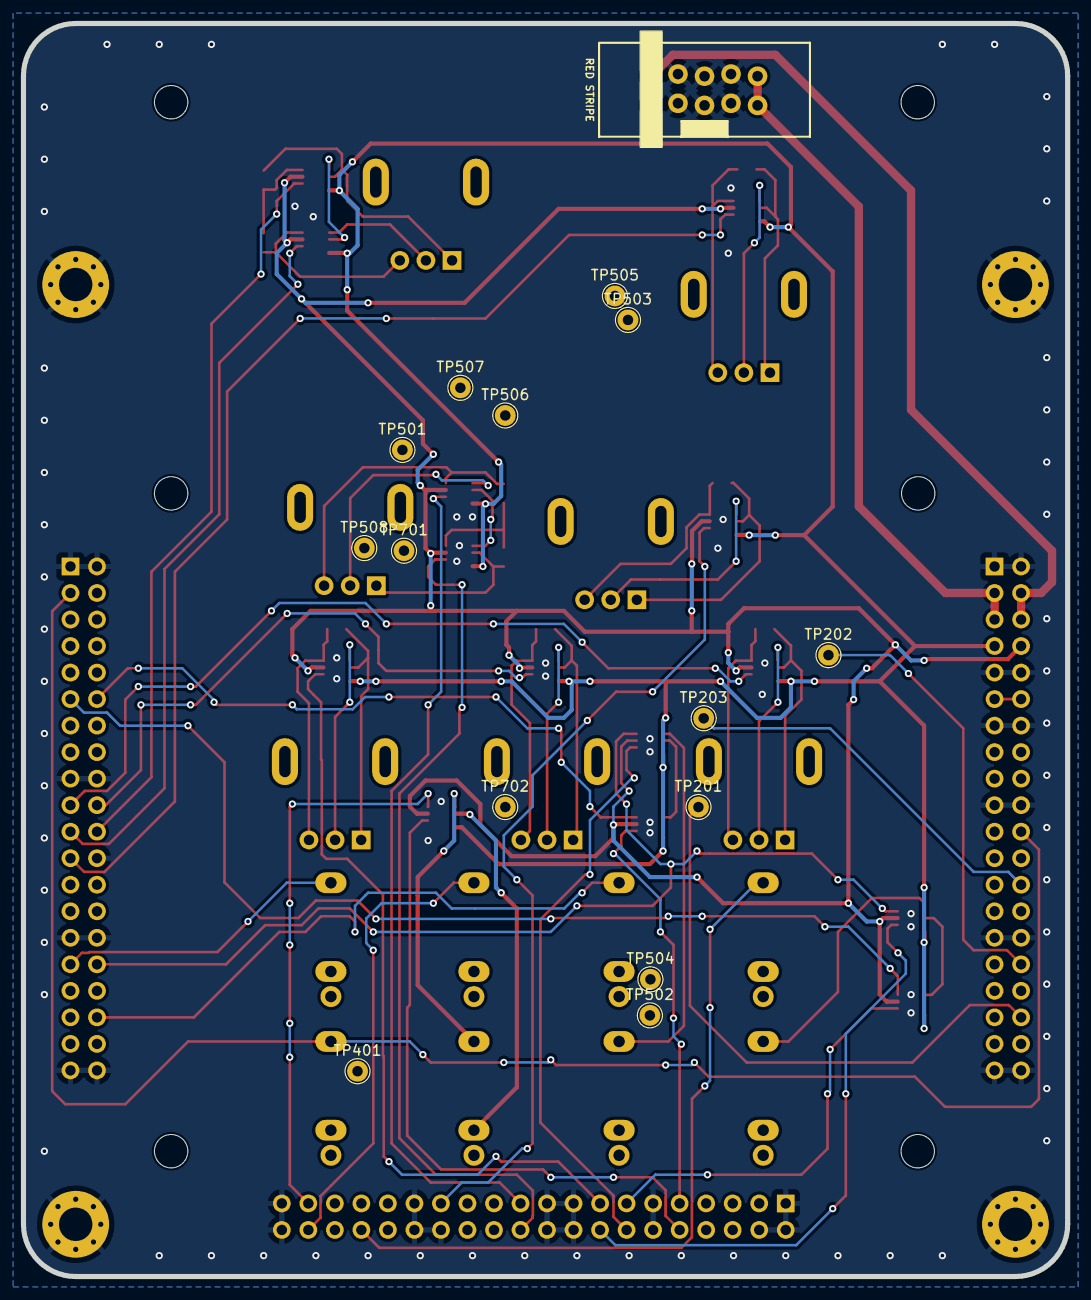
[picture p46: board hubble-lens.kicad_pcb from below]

Board: 2 copper layers, 100.0 x 120.0 mm, 66 parts (15 on the bottom side), 63 nets.

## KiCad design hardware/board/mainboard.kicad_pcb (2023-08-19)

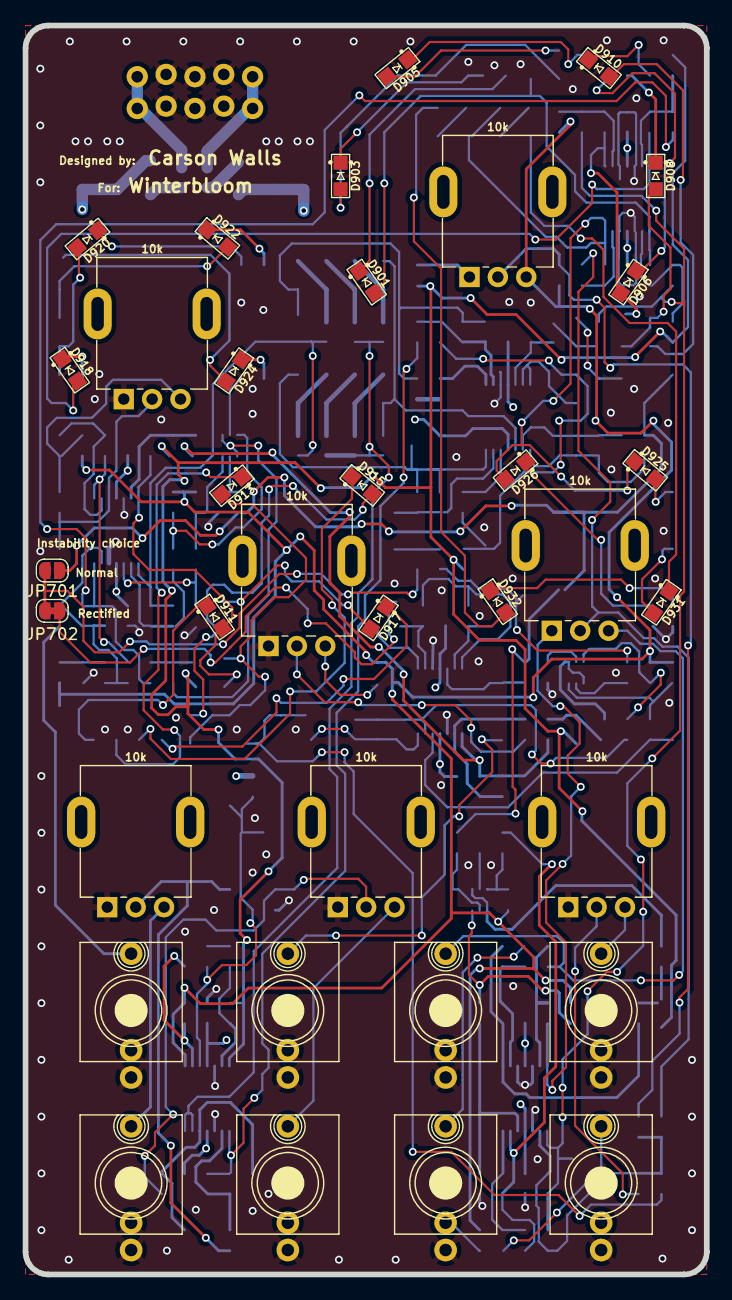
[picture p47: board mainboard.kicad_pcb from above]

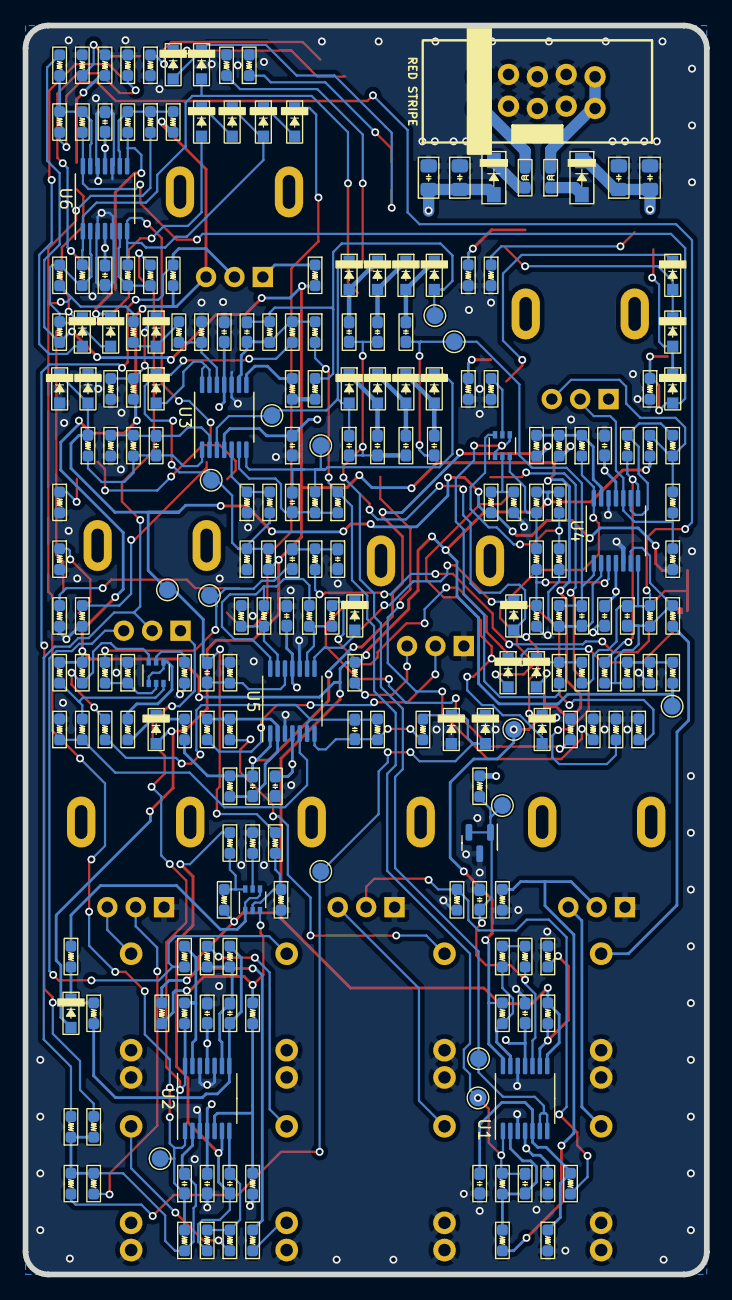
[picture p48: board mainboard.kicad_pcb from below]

Board: 4 copper layers, 60.0 x 110.0 mm, 266 parts (231 on the bottom side), 150 nets.

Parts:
C201, C202, C203, C204: 10u; C_0805_HandSolder
C205, C206, C207, C208, C209, C210, C211, C212, C213, C214, C215, C216, C217: 100n; C_0603_HandSolder
C301, C302, C503, C504, C505, C506, C507, C508, C509: 1n; C_0603_HandSolder
C401, C510: 100p; C_0603_HandSolder
C501, C502, C702: 220p; C_0603_HandSolder
C601, C704, C801: 330p; C_0603_HandSolder
C602, C705: 68p; C_0603_HandSolder
C701, C703: 220n; C_0603_HandSolder
C802: 10p; C_0603_HandSolder
D201, D202: 30V; D_SOD-123+SOD-123F
D501, D502, D503, D504, D505, D506, D507, D508, D509, D510, D511, D512, D601, D701, D702, D703, D704, D801, D902, D904, D907, D909, D912, D914, D916, D919, D921, D923, D927, D928, D929, D930: BAS315; D_SOD-323
D901, D903, D905, D906, D908, D910, D918, D920, D922, D925, D931: BLUE; LED_0805_Kingbright_APT2012
D911, D913, D915, D917, D924, D926, D932: RED; LED_0805_Kingbright_APT2012
FB201, FB202: 1k @ 100MHz; L_0603_HandSolder
J201: Power; Eurorack_Power_2x5_Shrouded_Lock
J301, J302, J401, J402, J601, J701, J801, J802: AudioJack_WQP518MA_Compact_S
JP701: SolderJumper_2_Open; SolderJumper-2_P1.3mm_Open_RoundedPad1.0x1.5mm
JP702: SolderJumper_2_Bridged; SolderJumper-2_P1.3mm_Bridged_RoundedPad1.0x1.5mm
Q601, Q701, Q801: BCM847; SOT-363_SC-70-6
R201, R203, R303, R306, R502, R515, R516, R519, R603, R604, R605, R612, R704, R705, R713, R722, R804, R815, R906, R912, R919, R926, R931, R932: 1k; R_0603_HandSolder
R202, R302, R305, R403, R404, R505, R606, R607, R609, R610, R611, R702, R710, R711, R712, R914, R927, R928: 100k; R_0603_HandSolder
R204, R405, R409, R518, R802, R803: 68k; R_0603_HandSolder
R205, R206, R720, R721: 220k; R_0603_HandSolder
R301, R304, R501, R504, R602, R709, R903, R909: 5k6; R_0603_HandSolder
R401, R517, R614, R619, R620, R718, R719: 3k9; R_0603_HandSolder
R402, R706, R707, R801: 39k; R_0603_HandSolder
R406, R407, R507, R621, R622, R902, R922: 33k; R_0603_HandSolder
R408, R601, R613, R701, R703, R714, R805, R806, R811, R812, R901, R907, R908, R913, R915, R920: 10k; R_0603_HandSolder
R503, R608, R813, R814, R921: 330k; R_0603_HandSolder
R506, R508, R509, R510, R511, R512, R513, R514, R617, R618, R716, R717, R809, R810: 20k; R_0603_HandSolder
R615, R616, R708, R715, R807, R808: 100R; R_0603_HandSolder
R904, R910, R917, R924, R929, R930: 1k5; R_0603_HandSolder
R905, R911, R918, R925: 1.2k; R_0603_HandSolder
R916, R923: 1.8k; R_0603_HandSolder
RV301, RV302, RV401, RV402, RV403, RV601, RV701: 10k; Potentiometer_Alpha_R0904N
TP201, TP202, TP203, TP401, TP501, TP502, TP503, TP504, TP505, TP506, TP507, TP508, TP701, TP702: TestPoint_Pad_D1.5mm
U1, U2, U3, U4, U5, U6: TL074; TSSOP-14_4.4x5mm_P0.65mm
U201: TL431A; SOT-23

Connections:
+8VREF: R205.1, R402.1, R504.1, R601.1, R602.2, R617.2, R618.1, R709.2, R716.2, R717.1, R801.2, R809.2, R810.1, R908.2, RV401.3, TP202.1, U1.8
+12V: C201.1, C203.1, C206.2, C208.2, C210.2, C212.2, C214.2, C216.2, D201.1 (K), R201.1, U1.4 (V+), U2.4 (V+), U3.4 (V+), U4.4 (V+), U5.4 (V+), U6.4 (V+)
-8VREF: D601.2 (A), D702.2 (A), D801.2 (A), R206.1, R401.2, R506.2, R902.2, R914.2, R921.2, TP203.1, U1.14
-12V: C202.1, C204.1, C207.2, C209.2, C211.2, C213.2, C215.2, C217.2, D202.2 (A), U1.11 (V-), U2.11 (V-), U3.11 (V-), U4.11 (V-), U5.11 (V-), U6.11 (V-)
/Cutoff CV Driver/CUTOFF_OUT: C401.1, R409.2, R501.2, R901.2, R907.2, TP401.1, U2.1
/Cutoff CV Driver/FM1_OUT: R406.2, R927.2, RV402.2
/Cutoff CV Driver/INSTABILITY_IN: D703.1 (K), D704.2 (A), R408.2, R722.1, TP702.1
/Filter Core/HIGH_PASS_IN: C504.2, C505.2, C506.2, C507.2, C508.2, TP504.1, U1.6 (-), U1.7
/Filter Core/LOW_PASS_IN: C301.1, R303.1, R509.2, R510.2, TP502.1, U1.1
/Filter Core/OUT: C701.2, D511.1 (K), D512.2 (A), JP701.1 (A), R519.2, R614.2, R805.1, TP508.1
/Filter Core/RESONANCE_IN: C503.2, C509.2, C602.1, R622.1, TP503.1, U4.1
/Instability VCA/INSTABILITY_CV_OUT: C704.1, R712.1, R713.2, R913.2, U5.1
/LED Drivers/RESONANCE_CV_IN: C601.1, R611.1, R612.2, R920.2, U4.7
/Power/2.5v unbuffered: C205.2, R201.2, R203.1, TP201.1, U1.10 (+), U201.1 (K), U201.2 (REF)
/Resonance VCA/Resonance_CV: J601.T (Tip), R608.2
/Resonance VCA/Resonance_Offset: R601.2, R603.2, R609.2
/Resonance VCA/Resonance_Potentiometer: R607.1, R610.2, U4.8
GND: C201.2, C202.2, C203.2, C204.2, C205.1, C206.1, C207.1, C208.1, C209.1, C210.1, C211.1, C212.1, C213.1, C214.1, C215.1, C216.1, C217.1, C302.2, C702.2, D511.2 (A), D512.1 (K), D703.2 (A), D704.1 (K), J201.3 (GND), J201.4 (GND), J201.5 (GND), J201.6 (GND), J201.7 (GND), J201.8 (GND), J301.S (Sleeve), J301.TN (Tip_normalize), J302.S (Sleeve), J302.TN (Tip_normalize), J401.S (Sleeve), J401.TN (Tip_normalize), J402.S (Sleeve), J402.TN (Tip_normalize), J601.S (Sleeve), J601.TN (Tip_normalize), J701.S (Sleeve), J701.TN (Tip_normalize), J801.S (Sleeve), J802.S (Sleeve), R202.2, R301.2, R304.2, R306.2, R502.2, R505.2, R507.1, R512.1, R517.1, R603.1, R605.2, R615.2, R616.1, R621.2, R701.2, R702.1, R708.2, R715.1, R720.2, R807.2, R808.1, R813.2, R904.2, R905.2, R906.2, R910.2, R911.2, R912.2, R916.2, R917.2, R918.2, R919.2, R923.2, R924.2, R925.2, R926.2, R929.2, R930.2, R931.2, R932.2, RV301.1, RV302.1, RV403.1, RV601.1, RV701.1, U1.3 (+), U1.12 (+), U2.3 (+), U2.10 (+), U2.12 (+), U3.10 (+), U4.5 (+), U4.12 (+), U5.3 (+), U5.10 (+), U6.3 (+), U6.5 (+), U6.10 (+), U6.12 (+), U201.3 (A)
unnamed: C510.1, R518.2, R519.1, U3.1
unnamed: C702.1, C703.2, R706.1
unnamed: C703.1, R707.1, TP701.1
unnamed: C705.1, R721.1, R722.2, U5.7
unnamed: C801.1, R803.1, R804.2, U2.8
unnamed: C802.2, R814.1, R815.2, U2.7
unnamed: D201.2 (A), FB201.1
unnamed: D202.1 (K), FB202.1
unnamed: D501.2 (A), R501.1, R503.2
unnamed: D501.1 (K), R502.1, R504.2
unnamed: D502.2 (A), U3.13 (-), U3.14
unnamed: D502.1 (K), R506.1, R507.2, R508.2, R511.2, TP501.1
unnamed: C501.1, D503.2 (A), R513.1, R515.1, TP505.1
unnamed: C503.1, D503.1 (K), D504.2 (A)
unnamed: C504.1, D504.1 (K), D505.2 (A)
unnamed: C505.1, D505.1 (K), D506.2 (A)
unnamed: C506.1, D506.1 (K), D507.2 (A), TP507.1, U3.3 (+)
unnamed: C507.1, D507.1 (K), D508.2 (A)
unnamed: C508.1, D508.1 (K), D509.2 (A)
unnamed: C509.1, D509.1 (K), D510.2 (A)
unnamed: C502.1, D510.1 (K), R514.1, TP506.1, U3.7
unnamed: D601.1 (K), R612.1, R613.2
unnamed: D701.2 (A), U5.8
unnamed: D701.1 (K), JP702.2 (B), R705.1
unnamed: D702.1 (K), R713.1, R714.2
unnamed: D801.1 (K), R804.1, R806.2
unnamed: D901.2 (A), D902.2 (A), R903.1, U6.1
unnamed: D901.1 (K), R904.1
unnamed: D902.1 (K), D903.2 (A), D904.2 (A)
unnamed: D903.1 (K), R905.1
unnamed: D904.1 (K), D905.2 (A)
unnamed: D905.1 (K), R906.1
unnamed: D906.2 (A), D907.1 (K), R909.1, U6.8
unnamed: D906.1 (K), R910.1
unnamed: D907.2 (A), D908.2 (A), D909.1 (K)
unnamed: D908.1 (K), R911.1
unnamed: D909.2 (A), D910.2 (A)
unnamed: D910.1 (K), R912.1
unnamed: D911.2 (A), D912.2 (A), R915.1, U4.14
unnamed: D911.1 (K), R916.1
unnamed: D912.1 (K), D913.2 (A), D914.2 (A)
unnamed: D913.1 (K), R917.1
unnamed: D914.1 (K), D915.2 (A), D916.2 (A)
unnamed: D915.1 (K), R918.1
unnamed: D916.1 (K), D917.2 (A)
unnamed: D917.1 (K), R919.1
unnamed: D918.2 (A), D919.2 (A), R922.1, U6.14
unnamed: D918.1 (K), R923.1
unnamed: D919.1 (K), D920.2 (A), D921.2 (A)
unnamed: D920.1 (K), R924.1
unnamed: D921.1 (K), D922.2 (A), D923.2 (A)
unnamed: D922.1 (K), R925.1
unnamed: D923.1 (K), D924.2 (A)
unnamed: D924.1 (K), R926.1
unnamed: D925.2 (A), R929.1
unnamed: D925.1 (K), D926.2 (A), D927.1 (K), D928.2 (A), R928.1, U6.7
unnamed: D926.1 (K), R930.1
unnamed: D927.2 (A), D929.1 (K)
unnamed: D928.1 (K), D930.2 (A)
unnamed: D929.2 (A), D931.1 (K)
unnamed: D930.1 (K), D932.2 (A)
unnamed: D931.2 (A), R931.1
unnamed: D932.1 (K), R932.1
unnamed: FB201.2, J201.9 (+12V), J201.10 (+12V)
unnamed: FB202.2, J201.1 (-12V), J201.2 (-12V)
unnamed: J301.T (Tip), RV301.3
unnamed: J302.T (Tip), RV302.3
unnamed: J401.T (Tip), R403.2, RV402.3
unnamed: J402.T (Tip), RV403.3
unnamed: J701.T (Tip), R710.2
unnamed: J801.T (Tip), R802.2
unnamed: J801.TN (Tip_normalize), R801.1
unnamed: J802.T (Tip), R815.1
unnamed: JP701.2 (B), JP702.1 (A), R706.2
unnamed: Q601.2 (B), R614.1, R615.1
unnamed: Q601.5 (B), R616.2
unnamed: Q601.3 (C), R618.2, R620.2
unnamed: Q601.6 (C), R617.1, R619.2
unnamed: Q601.1 (E), Q601.4 (E), R613.1
unnamed: Q701.2 (B), R707.2, R708.1
unnamed: Q701.5 (B), R715.2
unnamed: Q701.3 (C), R717.2, R719.2
unnamed: Q701.6 (C), R716.1, R718.2
unnamed: Q701.1 (E), Q701.4 (E), R714.1
unnamed: Q801.2 (B), R805.2, R807.1
unnamed: Q801.5 (B), R808.2
unnamed: Q801.3 (C), R810.2, R812.2
unnamed: Q801.6 (C), R809.1, R811.2
unnamed: Q801.1 (E), Q801.4 (E), R806.1
unnamed: R203.2, R204.1
unnamed: R301.1, R302.2, RV301.2
unnamed: R304.1, R305.2, RV302.2
unnamed: R401.1, RV401.1
unnamed: R402.2, R405.1, RV401.2
unnamed: R404.1, RV402.1, U2.14
unnamed: R407.2, RV403.2
unnamed: R515.2, R516.1
unnamed: R516.2, U3.8
unnamed: R602.1, R604.1, R606.2, RV601.3
unnamed: R703.1, R704.2, U5.14
unnamed: R709.1, RV701.3
unnamed: R711.2, RV701.2
unnamed: C301.2, R302.1, R303.2, U1.2 (-)
unnamed: C302.1, R305.1, R306.1, U1.5 (+)
unnamed: R202.1, R205.2, U1.9 (-)
unnamed: R204.2, R206.2, U1.13 (-)
unnamed: C401.2, R405.2, R406.1, R407.1, R408.1, R409.1, U2.2 (-)
unnamed: R812.1, R813.1, U2.5 (+)
unnamed: C802.1, R811.1, R814.2, U2.6 (-)
unnamed: C801.2, R802.1, R803.2, U2.9 (-)
unnamed: R403.1, R404.2, U2.13 (-)
unnamed: C510.2, R517.2, R518.1, U3.2 (-)
unnamed: R511.1, R512.2, U3.5 (+)
unnamed: C502.2, R510.1, R514.2, U3.6 (-)
unnamed: C501.2, R508.1, R509.1, R513.2, U3.9 (-)
unnamed: R503.1, R505.1, U3.12 (+)
unnamed: R620.1, R621.1, U4.3 (+)
unnamed: C602.2, R619.1, R622.2, U4.2 (-)
unnamed: C601.2, R608.1, R609.1, R610.1, R611.2, U4.6 (-)
unnamed: R604.2, R605.1, RV601.2, U4.10 (+)
unnamed: R606.1, R607.2, U4.9 (-)
unnamed: R913.1, R914.1, R915.2, U4.13 (-)
unnamed: C704.2, R710.1, R711.1, R712.2, U5.2 (-)
unnamed: R719.1, R720.1, U5.5 (+)
unnamed: C705.2, R718.1, R721.2, U5.6 (-)
unnamed: R704.1, R705.2, U5.9 (-)
unnamed: C701.1, R702.2, U5.12 (+)
unnamed: R701.1, R703.2, U5.13 (-)
unnamed: R901.1, R902.1, R903.2, U6.2 (-)
unnamed: R927.1, R928.2, U6.6 (-)
unnamed: R907.1, R908.1, R909.2, U6.9 (-)
unnamed: R920.1, R921.1, R922.2, U6.13 (-)

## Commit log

2023-06-08 Initial Schematic Complete
    Initial schematic completed. Most component values selected.
    [Cutoff_CV_Driver.kicad_sch, Filter_Core.kicad_sch, Input_Drivers.kicad_sch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]
2023-06-30 Schematic getting closer to being finished
    Schematic should be close to being ready to assign MPNs.
    [Cutoff_CV_Driver.kicad_sch, Filter_Core.kicad_sch, Input_Drivers.kicad_sch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]
2023-07-11 BOM Consolidation
    [Cutoff_CV_Driver.kicad_sch, Filter_Core.kicad_sch, Input_Drivers.kicad_sch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]
2023-07-13 Updates for LED Drivers
    [Cutoff_CV_Driver.kicad_sch, Filter_Core.kicad_sch, Input_Drivers.kicad_sch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]
2023-07-13 Update for LED rings. Simulation Updated
2023-07-13 Few cleanups for LED drivers
    [LED_Drivers.kicad_sch, mainboard.kicad_sch]
2023-07-20 hardware: update schematic with footprints and preliminary MPNs
    [Cutoff_CV_Driver.kicad_sch, Filter_Core.kicad_sch, Input_Drivers.kicad_sch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]
2023-07-21 Slight Changes to Knob Positions
    [mainboard.kicad_pcb]
2023-07-25 Very first component layout.
    [Cutoff_CV_Driver.kicad_sch, Filter_Core.kicad_sch, Input_Drivers.kicad_sch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]
2023-07-27 First Draft of layout V2 (All components facing the same way)
    [Cutoff_CV_Driver.kicad_sch, Filter_Core.kicad_sch, LED_Drivers.kicad_sch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]
2023-08-03 Initial Layout Complete
    [mainboard.kicad_pcb]
2023-08-13 Rough Draft of Routing Complete. Ugly but Passes DRC
    [Cutoff_CV_Driver.kicad_sch, Filter_Core.kicad_sch, Input_Drivers.kicad_sch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]
2023-08-13 Slight routing improvements.
    [Instability_VCA.kicad_sch, mainboard.kicad_pcb]
2023-08-13 hardware: minor routing changes: pull some vias back from the board edge, move test points, move vias back from pot mounting pads
    [mainboard.kicad_pcb]
2023-08-17 Moved +-12v to internal layer, cleaned up silkscreen
    [mainboard.kicad_pcb]
2023-08-17 Some minor routing improvements
    [mainboard.kicad_pcb]
2023-08-17 More minor changes
    [mainboard.kicad_pcb]
2023-08-17 hardware: reduce size of power traces, give vias a little more clearance
    [mainboard.kicad_pcb]
2023-08-19 Added stitching vias and cleaned various things up.
    [mainboard.kicad_pcb]
2023-08-20 hardware: add silkscreen decorations
2023-08-22 Final touches before being ready for ordering
    [Filter_Core.kicad_sch, Instability_VCA.kicad_sch, LED_Drivers.kicad_sch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]
2023-09-14 hardware: minor fixes and aesthetic updates
    - Fix HP LEDs being backwards
    - Switch power header, pot, and jack footprints to longpad variants
    - Make the text size on the front side larger
    - Add "red" and "blue" text next to respective LEDs on front side
    - Adjusted zone thermal spoke for better connection to GND pads
    - Squished the solder jumpers for instability type closer together
    - Minor adjustments to traces to accommodate longpad footprints
    [Cutoff_CV_Driver.kicad_sch, Input_Drivers.kicad_sch, Instability_VCA.kicad_sch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]
2023-09-17 Updated Schematic
    -Added R935, R936, and Q901 to make resonance self oscillation LED turn on sharply
    -Moved D929, D930, and added R933, R934 to make FM1 LED more sensitive
    -Changed FM1 Attenuverter and added R410 and R411 to make FM1 Knob have some curve/deadzone
    -Changed Resonance VCA output and added R623 and R624 to make resonance VCA output higher voltage to avoid opamp offset being significant .
    -Added testing documents
    [Cutoff_CV_Driver.kicad_sch, Filter_Core.kicad_sch, Input_Drivers.kicad_sch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]
2023-09-17 Slight tweaks
    [Resonance_VCA.kicad_sch, mainboard.kicad_sch]
2023-09-26 Updated PCB to add and routed new components.
    [Cutoff_CV_Driver.kicad_sch, Filter_Core.kicad_sch, Input_Drivers.kicad_sch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]
2023-09-26 Very minor schematic text change
    [LED_Drivers.kicad_sch]
2023-09-28 Updated Prototype Tests
    [Filter_Core.kicad_sch]
2023-10-02 hardware: clear ERC issues, move BCM847 to the Winterbloom symbol library
    [LED_Drivers.kicad_sch, Output_VCA.kicad_sch, Resonance_VCA.kicad_sch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]
2023-10-02 hardware: remove vias in test points, small adjustments to track spacing, resolve DRC errors
2023-10-02 hardware: initial hubble lens project
    [hubble-lens.kicad_pcb, hubble-lens.kicad_sch]
2023-10-02 hardware: add hubble notes
    [hubble-lens.kicad_sch]
2023-10-03 Rough Draft for Hubble Lens Schematic Complete
    [Knob_Multiplexers.kicad_sch, hubble-lens.kicad_sch]
2023-10-03 Minor schematic fixes
    [hubble-lens.kicad_sch]
2023-10-04 Rough Draft of PCB for Hubble Lens
    [Knob_Multiplexers.kicad_sch, hubble-lens.kicad_pcb, hubble-lens.kicad_sch]
2023-10-11 Lots of various small changes after reviewing the checklist.
    [Cutoff_CV_Driver.kicad_sch, Filter_Core.kicad_sch, Input_Drivers.kicad_sch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]
2023-10-13 hardware: add trans rights to back soldermask
2023-10-13 hardware: refill zones, plot gerbers for v1
2023-10-13 hardware: refill zones and plot gerbers for the hubble lens
    [hubble-lens.kicad_pcb]
2023-10-26 Replace 3904 with 3906 transistor and swap base and collector connection
    [LED_Drivers.kicad_sch]
2023-10-26 Replace 820R and 1k2 resistors with 1k resistors
    [LED_Drivers.kicad_sch]
2023-11-09 factory: initial pass at interfacing with Hubble lens
2023-11-09 factory: more work on lens interaction
2023-11-10 hardware: add MPNs, DigiKey part numbers, and LCSC part numbers for all BOM items
    [Cutoff_CV_Driver.kicad_sch, Filter_Core.kicad_sch, Input_Drivers.kicad_sch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]
2023-11-10 hardware: change C702 from 220pF to 330pF and C705 from 68pF to 100pF to reduce unique values
    [Salt_VCA.kicad_sch]
2023-11-10 hardware: update schematic fonts/text sizes, some slight readability improvements
    [Cutoff_CV_Driver.kicad_sch, Filter_Core.kicad_sch, Input_Drivers.kicad_sch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]
2023-11-12 hardware: add hubble lens board holder
2023-11-25 hardware: use new Winterbloom sheet layout
    [Cutoff_CV_Driver.kicad_sch, Filter_Core.kicad_sch, Input_Drivers.kicad_sch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]
2024-01-12 hardware: fixup board holder
2024-01-17 user guide: add audio samples
2024-01-17 user guide: add audio samples to guide
2024-01-18 user guide: normalize all audio samples, add more samples
2024-01-18 user guide: Fix title of drum effects sound sample
2024-01-30 user guide: update audio samples with better normalization
2024-01-31 user guide: update power connection image, remove oshwa boilerplate until we have the cert
2024-01-31 user guide: add pdf of schematic
2024-02-01 factory: tweak salt and reso tests to be more resilient to device-specific quirks
2024-02-13 Schematic and PCB updates to add offset trim
    [Input_Drivers.kicad_sch, Power.kicad_sch]
2024-02-13 hardware: finalize v3
    - Updated version number and release date
    - Swapped TL074C to TL074H
    [Cutoff_CV_Driver.kicad_sch, Filter_Core.kicad_sch, Input_Drivers.kicad_sch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]
2024-02-13 hardware: update schematic pdf
2025-01-30 hardware: Added faceplate
    [faceplate.kicad_pcb]

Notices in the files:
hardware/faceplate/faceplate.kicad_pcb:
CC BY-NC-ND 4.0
